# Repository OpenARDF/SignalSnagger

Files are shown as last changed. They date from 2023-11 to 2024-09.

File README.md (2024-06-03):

# SignalSnagger
<b>Project Status</b>

SignalSnagger is still in development. Product design and BOM contents are preliminary and incomplete.

<b>Concept</b>

SignalSnagger is an 80-meter band radio orienteering (ARDF) direction-finding receiver designed to operate in the Amateur Radio Service 3.5 MHz to 3.7 MHz frequency range. The receiver is designed to perform well in all common radio orienteering event formats: classic, sprint, and foxoring. SignalSnagger's frequency is stable and accurate using a precision temperature-compensated signal generator. A tuned loop with a "sense antenna," based on Dale Hunt's WB6BYU proven design, provides reliable signal-direction readings over a wide range of signal levels. This is an affordable, modern, competition-grade receiver design.

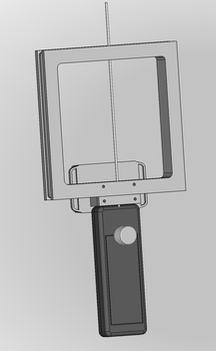
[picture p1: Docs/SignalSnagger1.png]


<b>Mechanical Design</b>

The mechanical design is optimized for simplicity, ruggedness, and ergonomic comfort. Left/right symmetry makes the receiver equally usable for left and right handers. Only the front knob (attached to a rotary encoder) extends beyond the walls of the chassis box, helping to minimize the risk of damage during transport or if dropped. Aside from the wires running to the battery, there is no point-to-point wiring - all connections are handled by PCB traces and parts mounted to the circuit board, eliminating unreliable point-to-point wiring. The headphone jack is on the bottom of the receiver, preventing water intrusion. The square antenna geometry makes for a stronger loop that can be readily fabricated using 3D printing. Switches for sense and configuration are recessed and immune to water penetration. The battery can be charged or replaced without opening the receiver chassis. If something breaks or wears out, all parts are readily available from online vendors, and the schematic diagram and BOM are provided, facilitating customer troubleshooting and repair.

<b>Electronics Design</b>

The electronics design is optimized to avoid part obsolescence and to provide high performance. SignalSlinger uses a Software Defined Radio design, utilizing a quadrature sampling detector to provide high dynamic range and to maximize software-upgradable features. A 25-MHz processor capable of sampling the baseband signal can filter and process the audio to achieve reliable signal strength indication and signal detection and supports DSP algorithms to achieve unparalleled SNR performance to detect weak signals deep in the noise.

<b>Free and Open Design</b>

The SignalSlinger project is 100% Open Source. All software and hardware design documents can be downloaded from this GitHub repository.

BOM: https://docs.google.com/spreadsheets/d/1Z3T1SeX6hfT8fjVtJgXu2S2YWHPFD_kywdSzAihOS8g/edit?usp=sharing

Also, check out SignalSnagger's sibling transmitter project: <a href="https://github.com/OpenARDF/SignalSlinger">SignalSlinger</a>.

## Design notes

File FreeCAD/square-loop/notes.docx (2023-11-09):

A square loop frame.

Grooved channels should allow the flat ribbon cable to lay flat in the channel with the pickup coax in a lower channel below the ribbon cable. No need to try forcing bending a flat cable into a round structure. The coax can be put in place first, then the ribbon cable on top. A much easier installation. The original design with a round loop had issues getting the ribbon cable installed and formed to match the curved surface simultaneously and keeping the coax well aligned in the bundle. It was very challenging to work with.

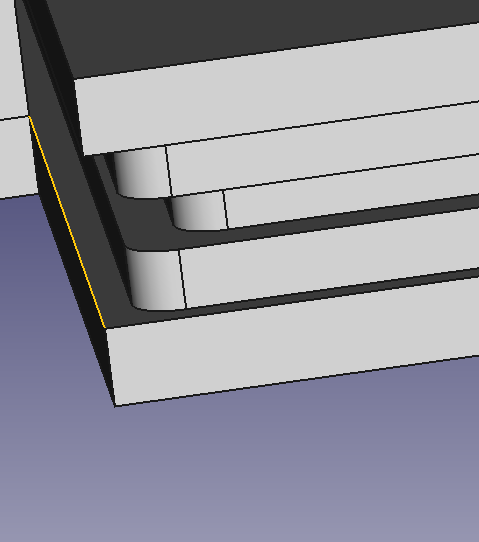
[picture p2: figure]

Flat Cable grove

Install coax first and

Then install Flat cable. This covers the coax.

Rounded edges to help cable make the bend.

Coax grove

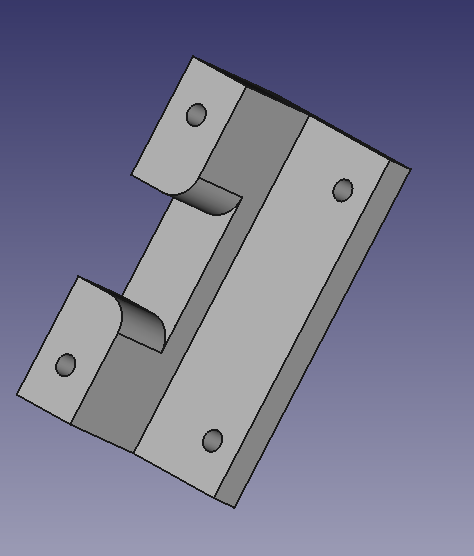
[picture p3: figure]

Bottom view of L block clamp showing rounded edges to help cable bend.

Loop main frame. No gluing or C clamps are required for the loop frame assembly. Printed as a single assembly. It will have more capture area than Dale’s original receiver. It should be closer to the rig expert FoxRex receiver.

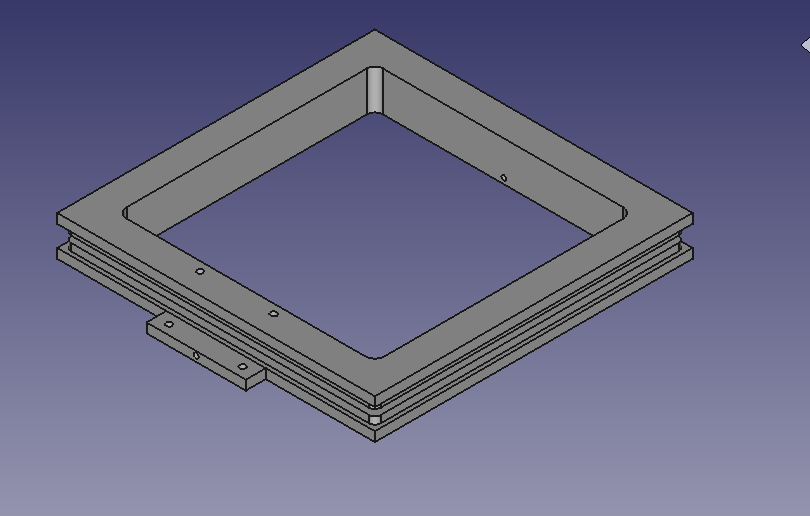
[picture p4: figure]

L block clamp.

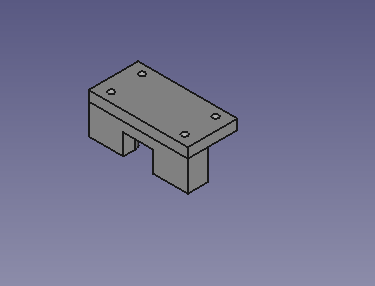
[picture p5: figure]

Complete assembly showing sense antenna installed.

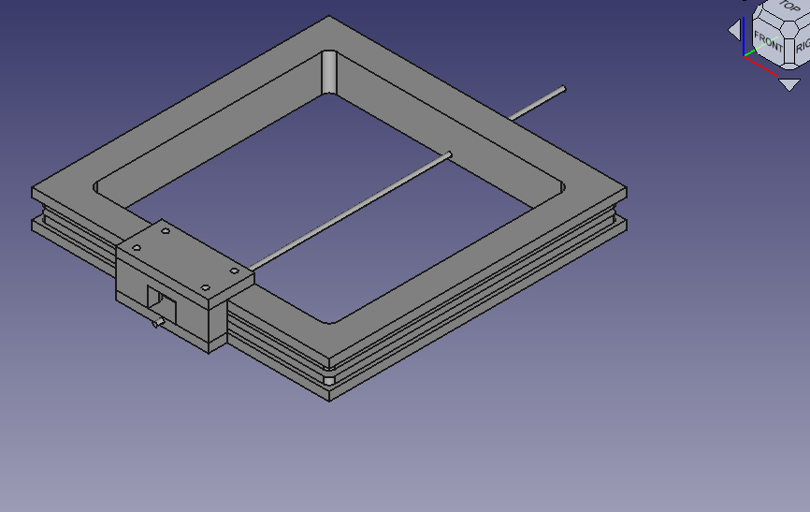
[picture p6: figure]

This will bolt onto the receiver box adaptor fixture.

Via the 4 bolt holes. 4 each 4-40 hardware. Attaches both the L clamp and loop frame to the receiver box adaptor using the 4 bolts.

Sense element is made from 220 mm length of Brass welding rod

Sense element

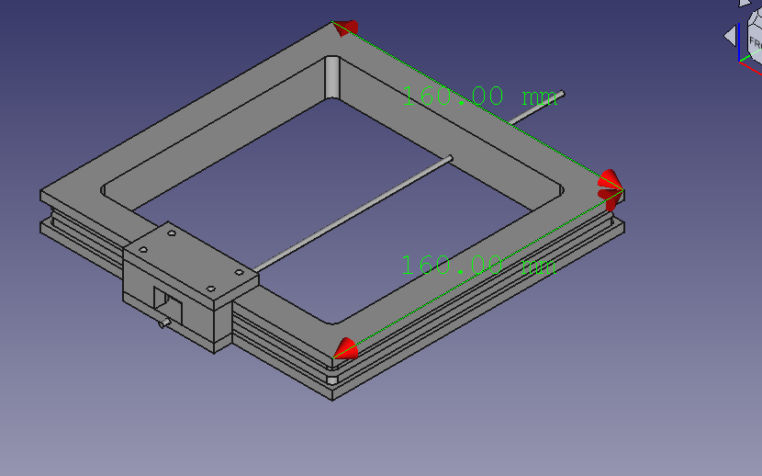
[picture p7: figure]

After running the Prusa printer slicer software using support material, the estimated print time will be 9H 35 seconds.

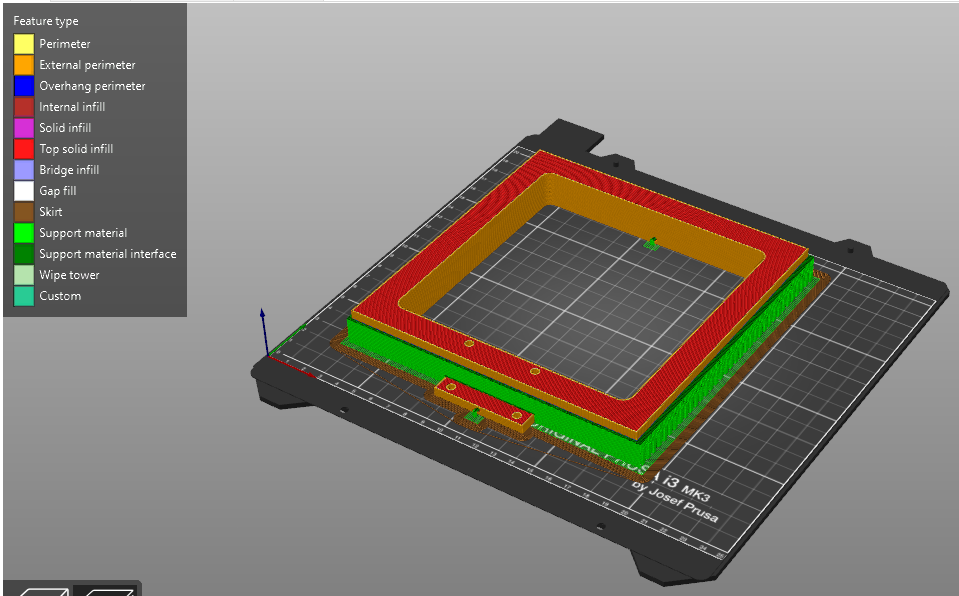
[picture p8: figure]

The Gcode files are for use with a Prusa printer.

The MF files are the Prusa printer slicer project files. If using another printer, start with the STL files and then prepare for your printer (slicing and adding printing supports for the loop.

Given the print size, I think it is possible to print a slide-on cover covering the ribbon. Will wait to see how the loop works (electrically and in the field) before designing that.

This design should be printable on most printers. I have a higher-end unit and print using PTEG material. It’s more robust and heat resistant.

A square loop frame is different from traditional round radio-O loops and is cool looking. It looks like photos from the early days of radio.

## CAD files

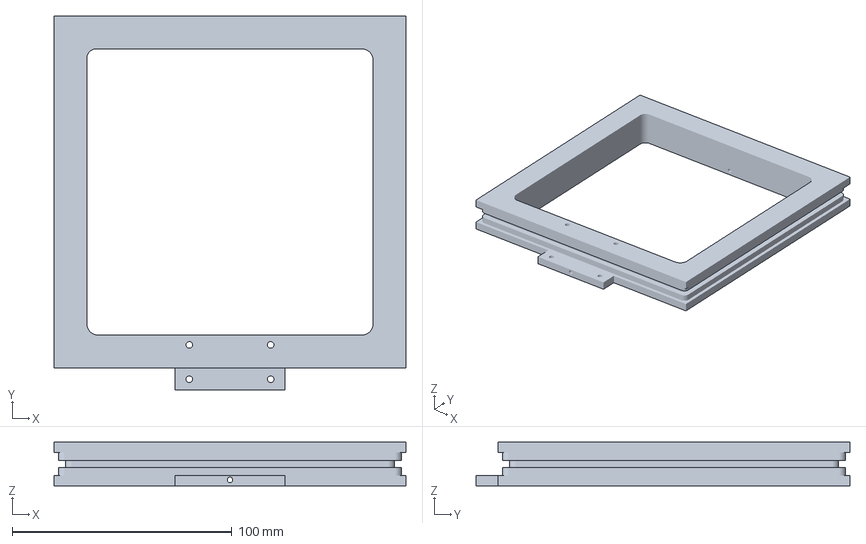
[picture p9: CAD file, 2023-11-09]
FreeCAD/square-loop/square-loop-loop-main-top.3mf
160.0 x 170.0 x 20.0 mm

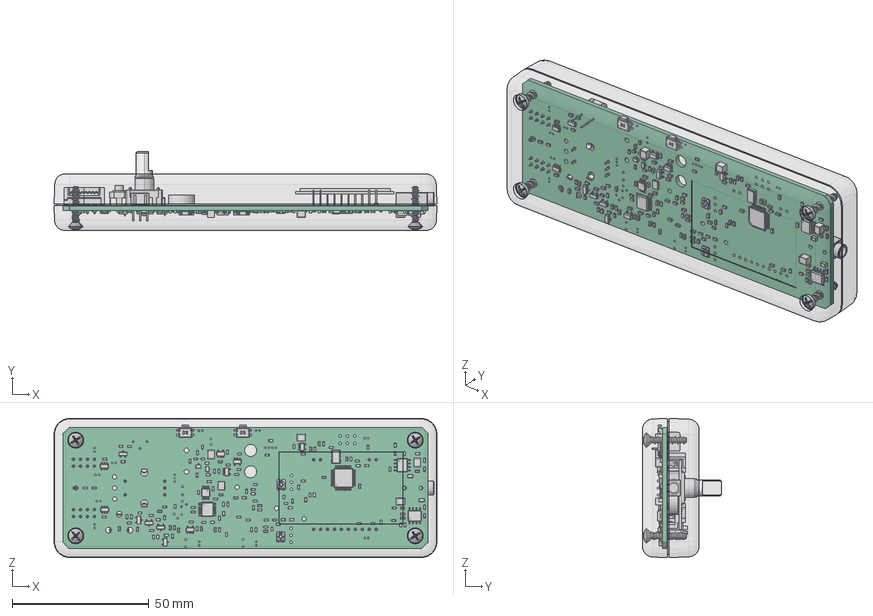
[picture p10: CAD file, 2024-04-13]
FreeCAD/PCB.FCStd
139.8 x 28.9 x 50.8 mm
Pcb_f029
C309_C_0603_1608Metric_5b6584633696 x 70
D202_D_SOD_523_5f1e31624493 x 3
R308_R_0603_1608Metric_2646eda285c6 x 56
Q104_SOT_23_06d05efaf5e9 x 5
C211_C_1210_3225Metric_024b47ac60aa x 4
U202_MSOP_10_3x3mm_P05mm_6a2b85d260ff
U304_SOIC_8_39x49mm_P127mm_a25c1b85c3f7 x 2
C912_C_0805_2012Metric_1626aba29b16 x 2
U103_SOT_23_5_ef80d484d645 x 5
U105_TSOP_6_165x305mm_P095mm_c201cc63ee81 x 2
P410002_Shrinkwrap_1 x 2
P410002_Shrinkwrap_002 x 2
P410002_Shrinkwrap_003 x 2
X202_Crystal_SMD_Abracon_ABM8G-4Pin_3.2x2.5mm_3b3a4259f167
U102_SSOP_16_44x52mm_P065mm_e96945418c2c
U201_TQFP_48_7x7mm_P05mm_968e8baed286
Q202_SOT_323_SC_70_05efad48121b x 2
L201_L_0603_1608Metric_e3fa5a9bdcec
TC33X-2-202E x 2
TC33X-2-202E001 x 2
TC33X-2-202E002 x 2
TC33X-2-202E003 x 2
TC33X-2-202E004 x 2
TC33X-2-202E005 x 2
TC33X-2-202E006 x 2
TC33X-2-202E007 x 2
Oscillator_SMD_Fox_FT5H_5.0x3.2mm
Oscillator_SMD_Fox_FT5H_5.0x3.2mm001
Oscillator_SMD_Fox_FT5H_5.0x3.2mm002
C103_top-cap_a8b6c266b834
SW203_pec12r-4225f-s0024_5a24d6cbfc16
D203_LED_0805_2012Metric_1174dec2679d x 2
U205_Body_sp_fa2d59fb00e0
69830_20P_BODY_1_AF0_1_AF0 x 2
69830_20P_COVER_1_AF0_1_AF0 x 2
69830_20P_BODY_1_AF0_1_AF0_1 x 2
69830_20P_COVER_1_AF0_1_AF0_1 x 2
J301_35RASMT2BHSNTRX_d01fbb62650b
T101_37-43_8862338c664e
RV101_3362A_TAA_384ee5cac117
KT-70C_KT-70TC001
SCREWS-HL5~8-BR
KT-70B_KT-70BXX
SCREWS-HL5~8-BR001
SCREWS-HL5~8-BR002
SCREWS-HL5~8-BR003

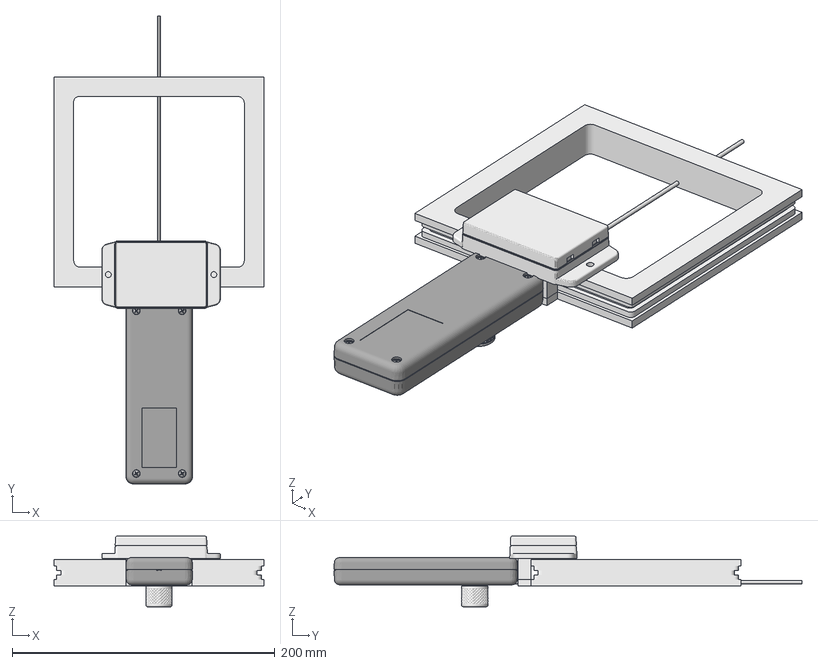
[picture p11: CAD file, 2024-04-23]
FreeCAD/square-loop/square-loop.FCStd
160.0 x 356.5 x 53.8 mm
lblock-top
loop-main-top
Pcb_f029
C309_C_0603_1608Metric_5b6584633696 x 70
D202_D_SOD_523_5f1e31624493 x 3
R308_R_0603_1608Metric_2646eda285c6 x 56
Q104_SOT_23_06d05efaf5e9 x 5
C211_C_1210_3225Metric_024b47ac60aa x 4
U202_MSOP_10_3x3mm_P05mm_6a2b85d260ff
U304_SOIC_8_39x49mm_P127mm_a25c1b85c3f7 x 2
C912_C_0805_2012Metric_1626aba29b16 x 2
U103_SOT_23_5_ef80d484d645 x 5
U105_TSOP_6_165x305mm_P095mm_c201cc63ee81 x 2
P410002_Shrinkwrap_1 x 2
P410002_Shrinkwrap_002 x 2
P410002_Shrinkwrap_003 x 2
X202_Crystal_SMD_Abracon_ABM8G-4Pin_3.2x2.5mm_3b3a4259f167
U102_SSOP_16_44x52mm_P065mm_e96945418c2c
U201_TQFP_48_7x7mm_P05mm_968e8baed286
Q202_SOT_323_SC_70_05efad48121b x 2
L201_L_0603_1608Metric_e3fa5a9bdcec
TC33X-2-202E x 2
TC33X-2-202E001 x 2
TC33X-2-202E002 x 2
TC33X-2-202E003 x 2
TC33X-2-202E004 x 2
TC33X-2-202E005 x 2
TC33X-2-202E006 x 2
TC33X-2-202E007 x 2
Oscillator_SMD_Fox_FT5H_5.0x3.2mm
Oscillator_SMD_Fox_FT5H_5.0x3.2mm001
Oscillator_SMD_Fox_FT5H_5.0x3.2mm002
C103_top-cap_a8b6c266b834
SW203_pec12r-4225f-s0024_5a24d6cbfc16
D203_LED_0805_2012Metric_1174dec2679d x 2
U205_Body_sp_fa2d59fb00e0
69830_20P_BODY_1_AF0_1_AF0 x 2
69830_20P_COVER_1_AF0_1_AF0 x 2
69830_20P_BODY_1_AF0_1_AF0_1 x 2
69830_20P_COVER_1_AF0_1_AF0_1 x 2
J301_35RASMT2BHSNTRX_d01fbb62650b
T101_37-43_8862338c664e
RV101_3362A_TAA_384ee5cac117
KT-70C_KT-70TC001
SCREWS-HL5~8-BR
KT-70B_KT-70BXX
SCREWS-HL5~8-BR001
SCREWS-HL5~8-BR002
SCREWS-HL5~8-BR003
450mAh LiPo
SN-23B_SN-23B-01
SN-23C_SN-23C-01
20mm

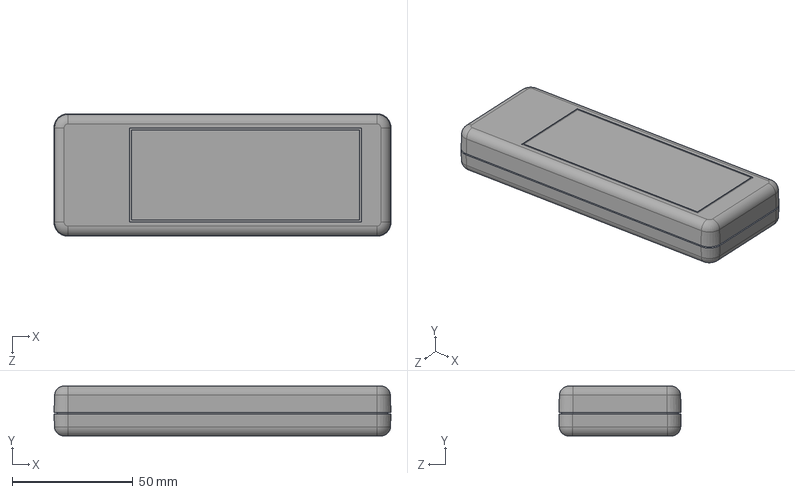
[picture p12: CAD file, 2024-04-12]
FreeCAD/KT-70XXT0 ASS'Y.STEP
139.8 x 20.7 x 50.8 mm
KT-70C_KT-70TC0
SCREWS-HL5~8-BR x 4
KT-70B_KT-70BXX

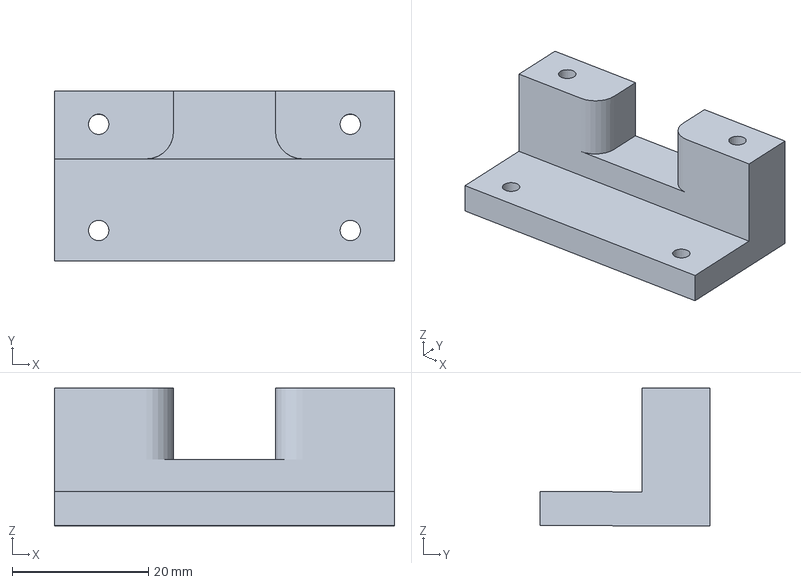
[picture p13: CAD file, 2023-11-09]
FreeCAD/square-loop/lblock-top.3mf
50.0 x 25.0 x 20.3 mm

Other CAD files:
FreeCAD/square-loop/lblock-top.stl
FreeCAD/square-loop/square-loop-loop-main-top.stl

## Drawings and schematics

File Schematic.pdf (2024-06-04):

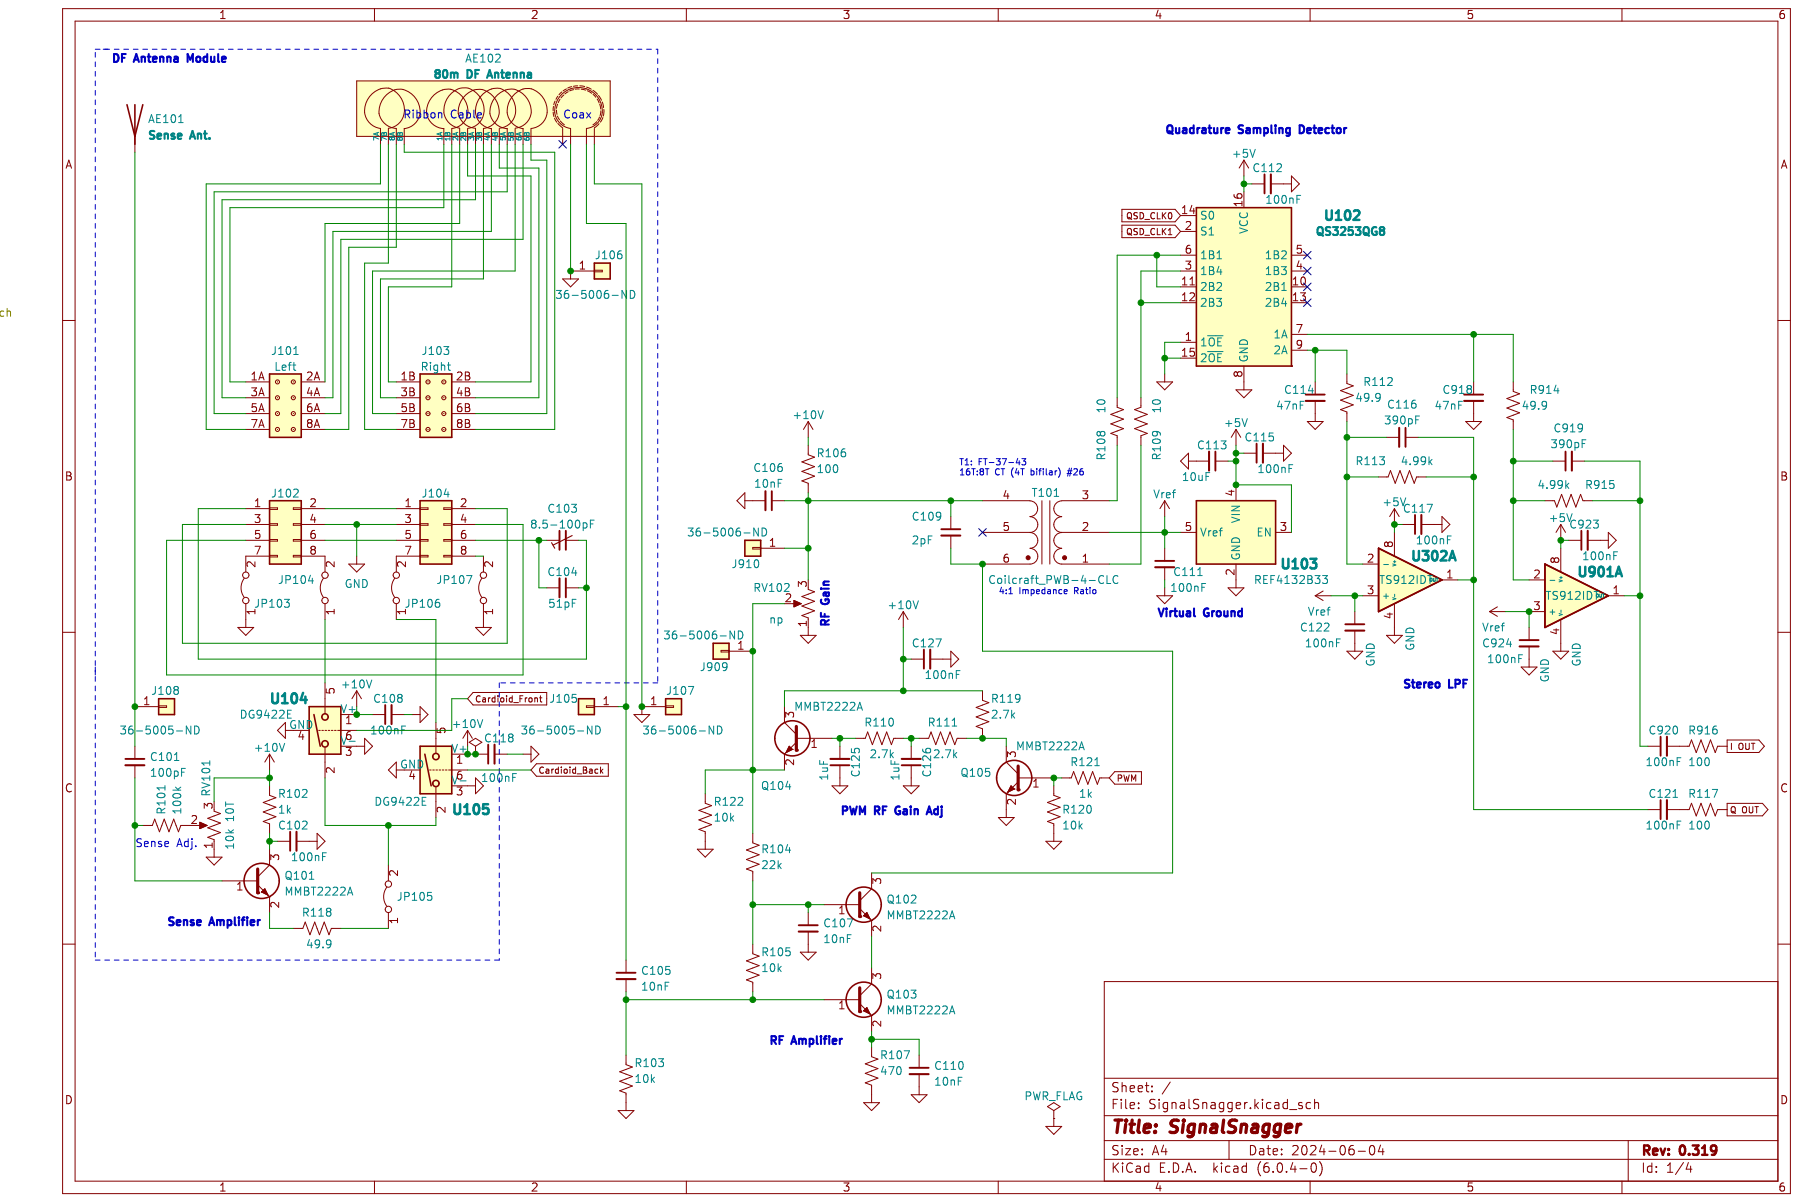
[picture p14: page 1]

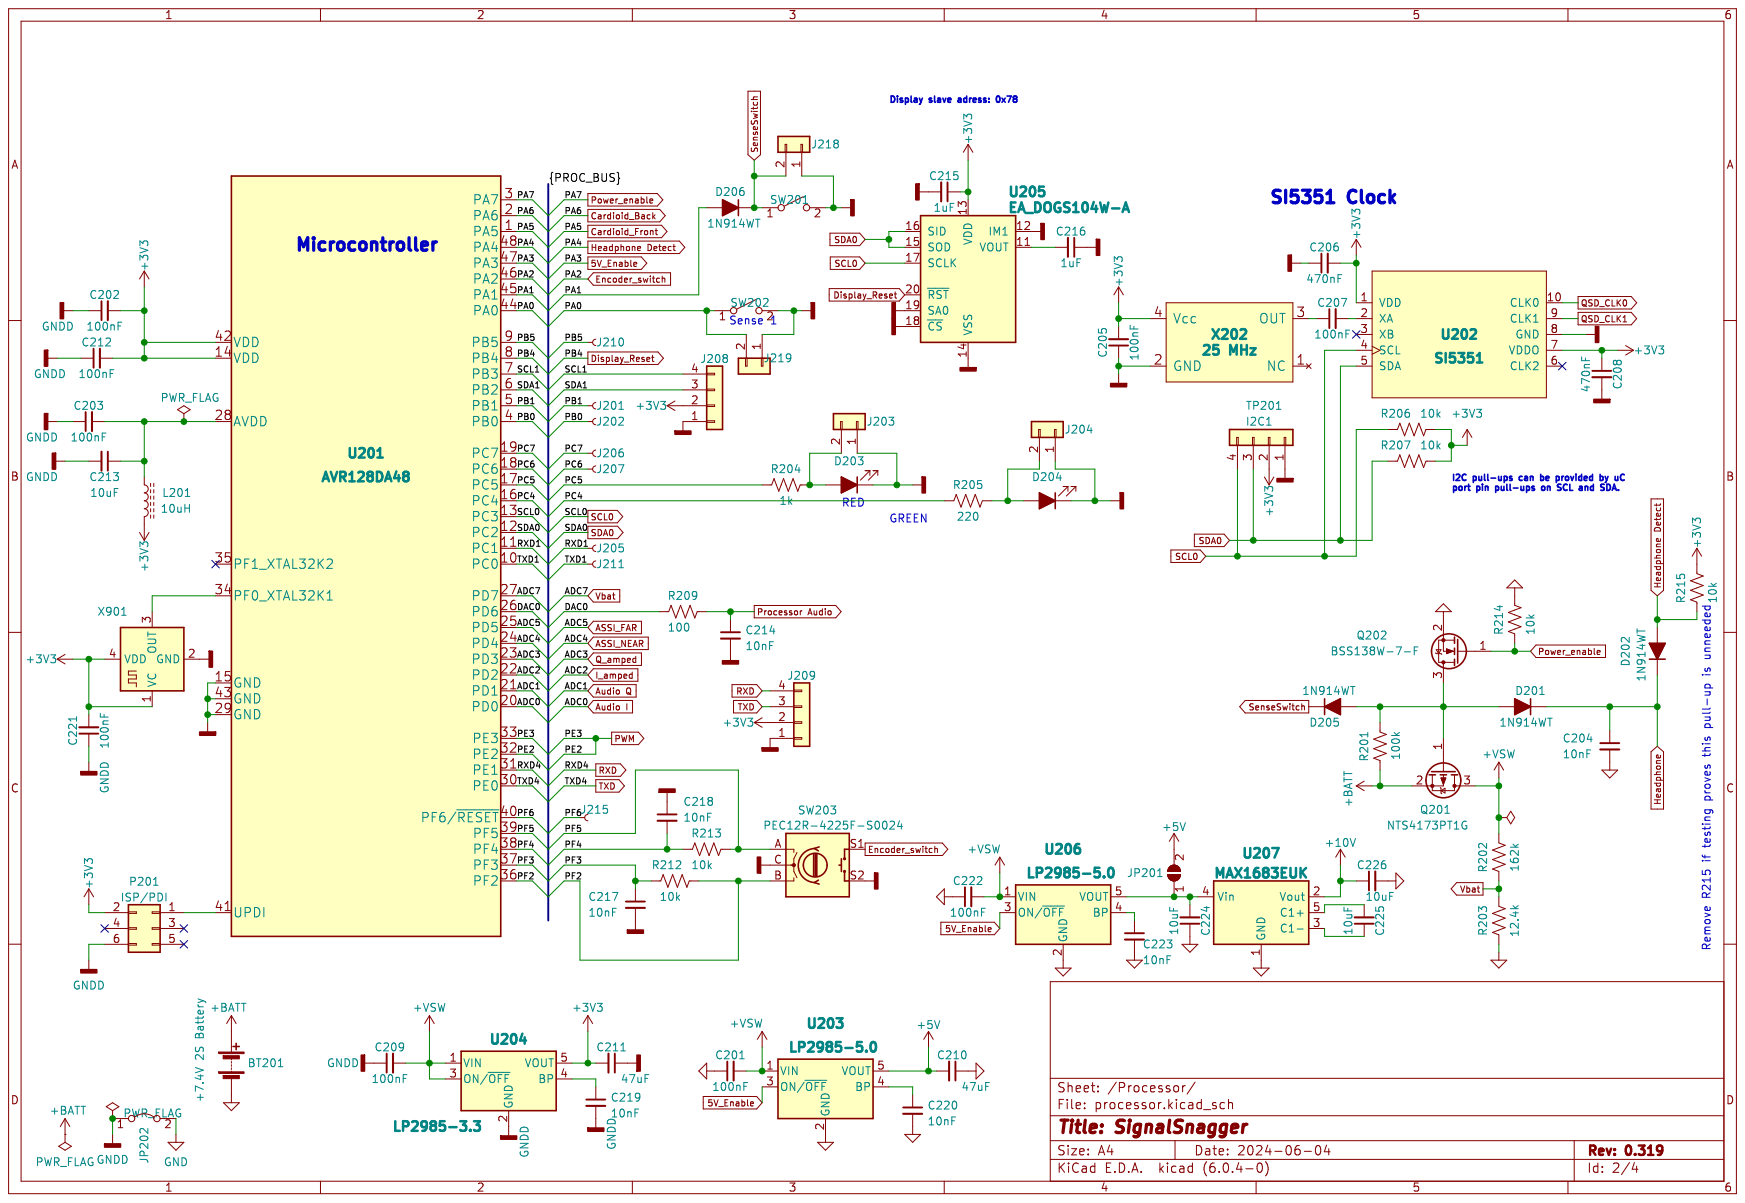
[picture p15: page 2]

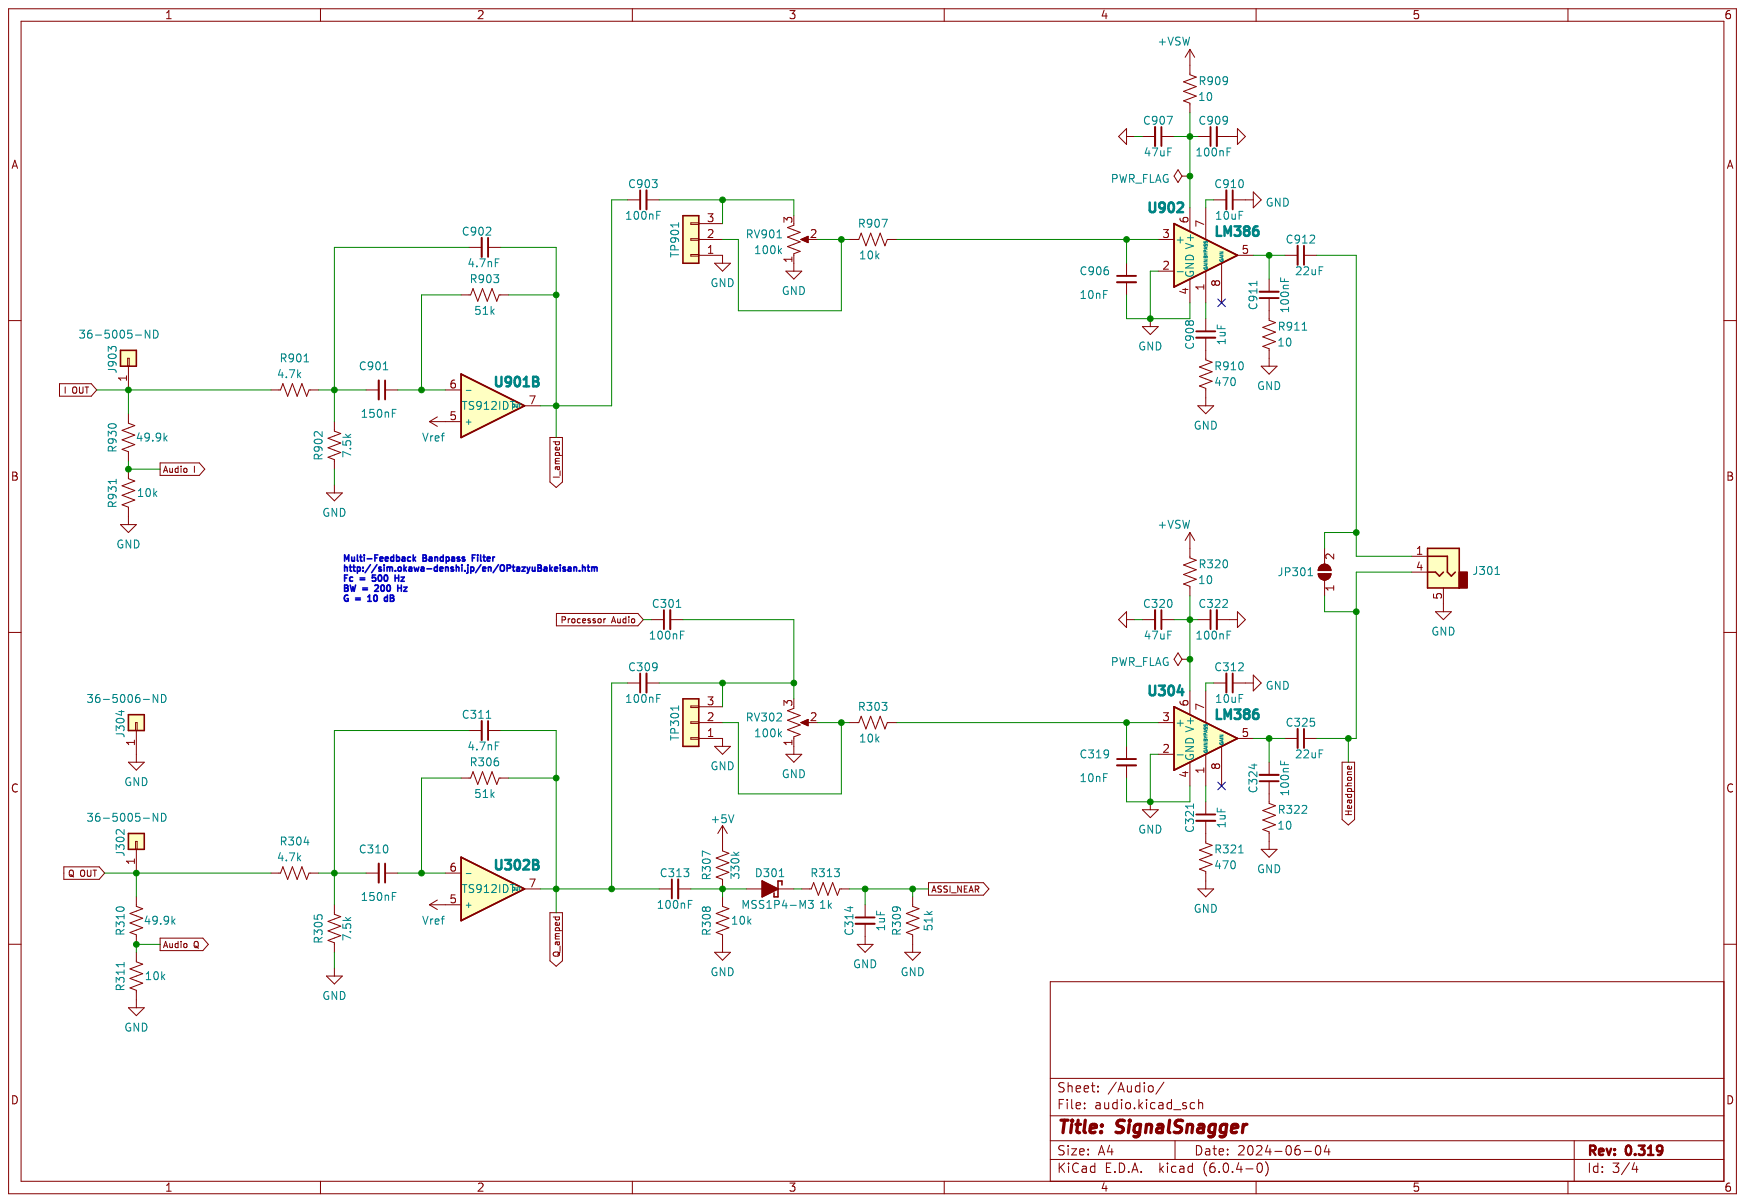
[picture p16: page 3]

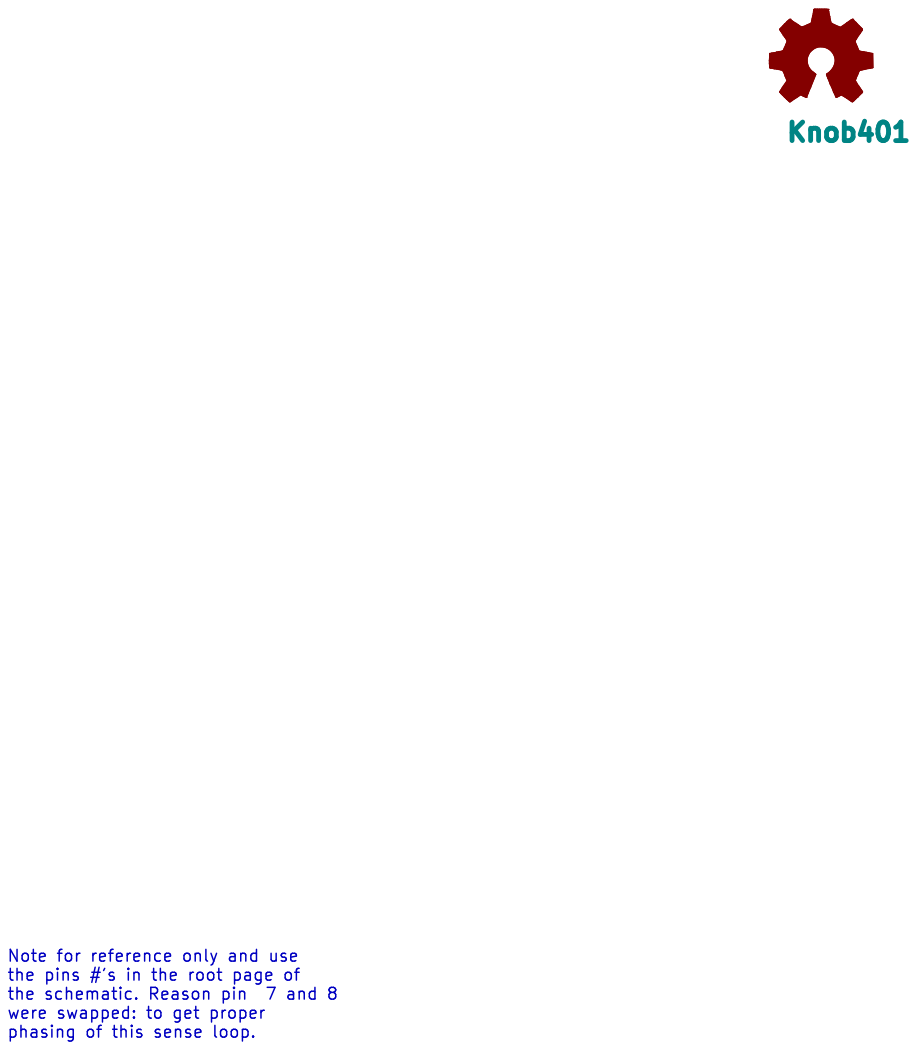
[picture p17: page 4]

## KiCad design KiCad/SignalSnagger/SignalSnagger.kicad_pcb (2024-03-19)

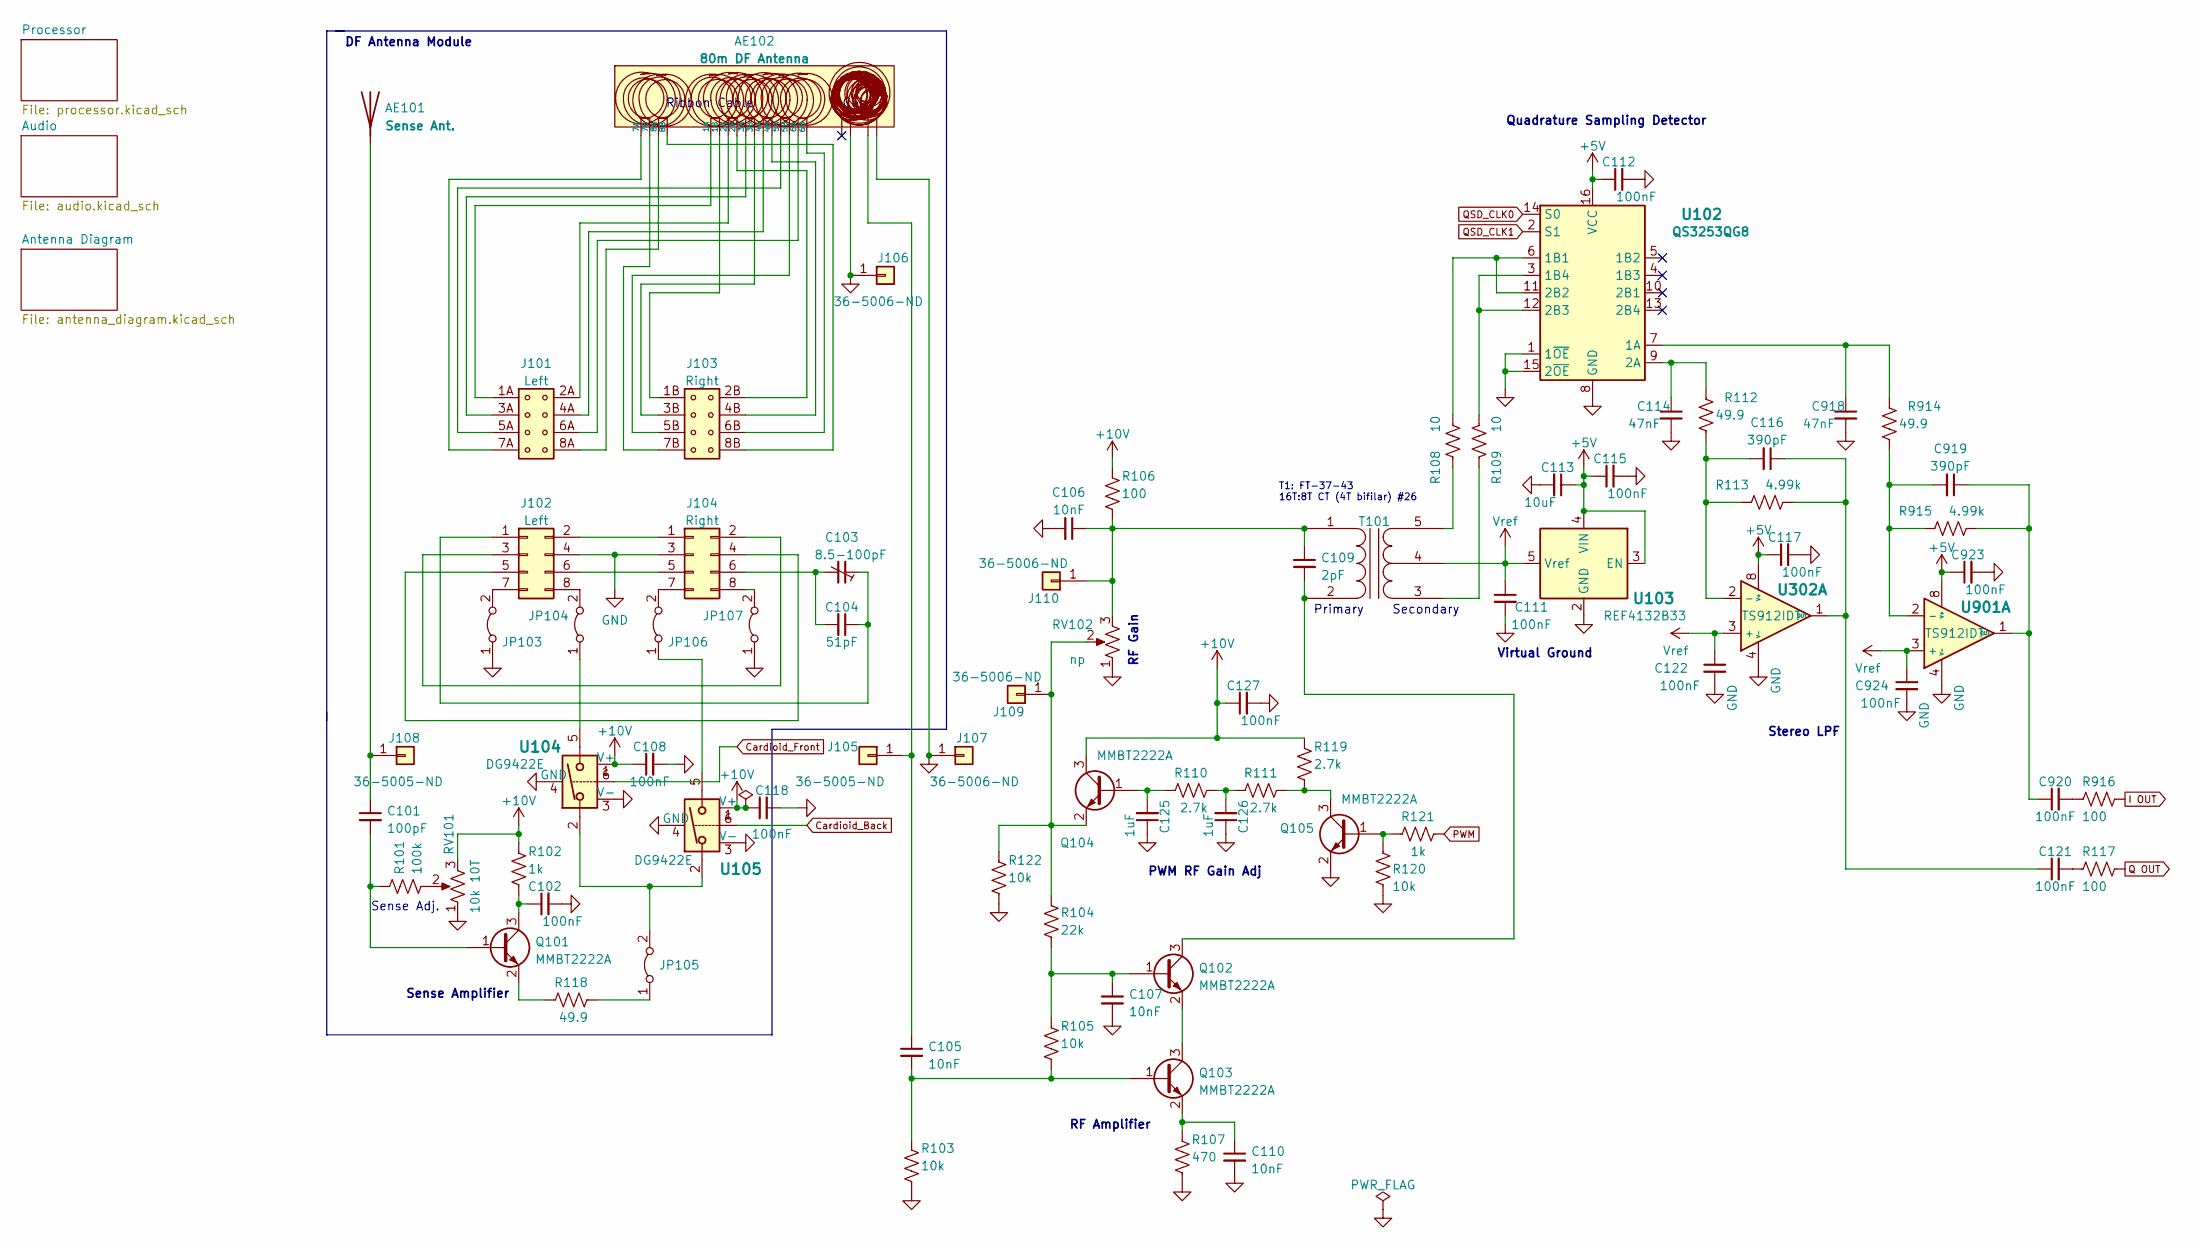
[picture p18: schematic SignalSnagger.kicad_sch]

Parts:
AE101: Sense Ant.; Dummy_Empty
AE102: 80m DF Antenna; Dummy_Empty
C101: 100pF; C_0603_1608Metric; Manufacturer PN CC0603JRNPO9BN101; Digi-Key Part No. 311-1069-1-ND
C102, C108, C111, C112, C115, C117, C118, C121, C122, C127, C920, C923, C924: 100nF; C_0603_1608Metric; Manufacturer PN CL10B104KA8NNNC; Digi-Key Part No. 1276-1006-1-ND
C103: 8.5-100pF; VC07B; Manufacturer PN CTC07RB-100; Digi-Key Part No. N/P
C104: 51pF; C_0603_1608Metric; Manufacturer PN CL10C510JB8NNNC; Digi-Key Part No. 1276-2310-1-ND
C105, C106, C107, C110: 10nF; C_0603_1608Metric; Manufacturer PN C0603X103J4HACAUTO; Digi-Key Part No. 399-C0603X103J4HACAUTOCT-ND
C109: 2pF; C_0603_1608Metric; Manufacturer PN 06035A2R0JAT2A; Digi-Key Part No. 478-11610-1-ND
C113: 10uF; C_0603_1608Metric; Manufacturer PN GRM188C81C106MA73D; Digi-Key Part No. 490-7198-1-ND
C114, C918: 47nF; C_0603_1608Metric; Manufacturer PN C0603X473J4RECAUTO7411; Digi-Key Part No. 399-C0603X473J4RECAUTO7411CT-ND
C116, C919: 390pF; C_0603_1608Metric; Manufacturer PN CC0603JRNPO9BN391; Digi-Key Part No. 311-1076-1-ND
C125, C126: 1uF; C_0603_1608Metric; Manufacturer PN CC0603KRX5R8BB105; Digi-Key Part No. 311-1445-1-ND
J101: Left; Dummy_Empty
J102: Left; PinHeader_2x04_P2.54mm_Vertical; Digi-Key Part No. N/P
J103: Right; Dummy_Empty
J104: Right; PinHeader_2x04_P2.54mm_Vertical; Digi-Key Part No. N/P
J105, J108: 36-5005-ND; Pin_D1.6mm_L8.5mm_W2.8mm_FlatFork; Digi-Key Part No. N/P
J106, J107, J109, J110: 36-5006-ND; Pin_D1.6mm_L8.5mm_W2.8mm_FlatFork; Digi-Key Part No. N/P
JP103, JP104, JP106, JP107: Digi-Key Part No. N/P
JP105: Jumper_2_Bridged; Jumper_THT-1x02_Bridged_Circular; Digi-Key Part No. N/P
Q101, Q102, Q103, Q104, Q105: MMBT2222A; SOT-23; Manufacturer PN SMMBT2222ALT1G; Digi-Key Part No. SMMBT2222ALT1GOSCT-ND
R101: 100k; R_0603_1608Metric; Manufacturer PN RC0603FR-07100KL; Digi-Key Part No. 311-100KHRCT-ND
R102, R121: 1k; R_0603_1608Metric; Manufacturer PN RC0603FR-071KL; Digi-Key Part No. 311-1.00KHRCT-ND
R103, R105, R120, R122: 10k; R_0603_1608Metric; Manufacturer PN RC0603FR-0710KL; Digi-Key Part No. 311-10.0KHRCT-ND
R104: 22k; R_0603_1608Metric; Manufacturer PN RC0603FR-0722KL; Digi-Key Part No. 311-22.0KHRCT-ND
R106, R117, R916: 100; R_0603_1608Metric; Manufacturer PN RC0603FR-07100RL; Digi-Key Part No. 311-100HRCT-ND
R107: 470; R_0603_1608Metric; Manufacturer PN RC0603FR-07470RL; Digi-Key Part No. 311-470HRCT-ND
R108, R109: 10; R_0603_1608Metric; Manufacturer PN RC0603FR-0710RL; Digi-Key Part No. 311-10.0HRCT-ND
R110, R111, R119: 2.7k; R_0603_1608Metric; Manufacturer PN RC0603FR-072K7L; Digi-Key Part No. 311-2.70KHRCT-ND
R112, R118, R914: 49.9; R_0603_1608Metric; Manufacturer PN ERJ-3EKF49R9V; Digi-Key Part No. P49.9HCT-ND
R113, R915: 4.99k; R_0603_1608Metric; Manufacturer PN RC0603FR-074K99L; Digi-Key Part No. 311-4.99KHRCT-ND
RV101: 10k 10T; Bourns_PV36W_Multiturn_Pot; Manufacturer PN PV36W103C01B00; Digi-Key Part No. 118-PV36W103C01B00-ND
RV102: np; PinHeader_1x03_P1.27mm_Vertical
T101: Transformer_1P_SS; FT-37_Core_3_windings_Horiz_TH; Digi-Key Part No. N/P
U102: QS3253QG8; SSOP-16_3.9x4.9mm_P0.635mm; Manufacturer PN PI5C3253QEX; Digi-Key Part No. PI5C3253QEXDICT-ND
U103: REF4132B33; SOT-23-5; Manufacturer PN REF4132B33DBVR; Digi-Key Part No. 296-REF4132B33DBVRCT-ND
U104, U105: DG9422E; TSOP-6_1.65x3.05mm_P0.95mm; Manufacturer PN DG9422EDV-T1-GE3; Digi-Key Part No. DG9422EDV-T1-GE3CT-ND
U302, U901: TS912IDT; SO-8_3.9x4.9mm_P1.27mm; Manufacturer PN TS912IDT; Digi-Key Part No. 497-6618-1-ND

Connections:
+5V: C112.1, C113.1, C115.1, C117.1, C923.1, U102.16 (VCC), U103.3 (EN), U103.4 (VIN), U302.8 (V+), U901.8 (V+); also elsewhere on the board
+10V: C108.1, C118.1, C127.1, Q104.3 (C), R102.1, R106.1, R119.1, RV101.3, U104.1 (V+), U105.1 (V+); also elsewhere on the board
Cardioid_Back: U105.6; also elsewhere on the board
Cardioid_Front: U104.6; also elsewhere on the board
GND: AE102.18, AE102.20, C102.2, C106.2, C107.2, C108.2, C110.2, C111.2, C112.2, C113.2, C114.2, C115.2, C117.2, C118.2, C122.2, C125.1, C126.1, C127.2, C918.2, C923.2, C924.2, J102.4, J104.3, J106.1, J107.1, JP103.1 (A), JP107.1 (A), Q105.2 (E), R103.2, R107.2, R120.2, R122.2, RV101.1, RV102.1, U102.1 (1~OE), U102.8 (GND), U102.15 (2~OE), U103.2 (GND), U104.3 (V-), U104.4 (GND), U105.3 (V-), U105.4 (GND), U302.4 (V-), U901.4 (V-); also elsewhere on the board
I OUT: R916.2; also elsewhere on the board
unnamed: AE101.1, C101.1, J108.1
unnamed: AE102.1 (7A), J101.7A (Pin_7)
unnamed: AE102.2 (7B), J103.7B (Pin_7)
unnamed: AE102.3 (8A), J101.8A (Pin_8)
unnamed: AE102.4 (8B), J103.8B (Pin_8)
unnamed: AE102.5 (1A), J101.1A (Pin_1)
unnamed: AE102.6 (1B), J103.1B (Pin_1)
unnamed: AE102.7 (2A), J101.2A (Pin_2)
unnamed: AE102.8 (2B), J103.2B (Pin_2)
unnamed: AE102.9 (3A), J101.3A (Pin_3)
unnamed: AE102.10 (3B), J103.3B (Pin_3)
unnamed: AE102.11 (4A), J101.4A (Pin_4)
unnamed: AE102.12 (4B), J103.4B (Pin_4)
unnamed: AE102.13 (5A), J101.5A (Pin_5)
unnamed: AE102.14 (5B), J103.5B (Pin_5)
unnamed: AE102.15 (6A), J101.6A (Pin_6)
unnamed: AE102.16 (6B), J103.6B (Pin_6)
unnamed 60: AE102.19, C105.1, J105.1; also elsewhere on the board
unnamed: C101.2, Q101.1 (B), R101.1
unnamed: C102.1, Q101.3 (C), R102.2
unnamed: C103.1, C104.1, J102.1
unnamed: C103.2, C104.2, J104.6
unnamed 65: C105.2, Q103.1 (B), R103.1, R105.2; also elsewhere on the board
unnamed: C106.1, C109.1, J110.1, R106.2, RV102.3, T101.1 (AA)
unnamed: C107.1, Q102.1 (B), R104.2, R105.1
unnamed: C109.2, Q102.3 (C), T101.2 (AB)
unnamed: C110.1, Q103.2 (E), R107.1
unnamed: C114.1, R112.2, U102.9 (2A)
unnamed: C116.1, C121.1, R113.1, U302.1 (OUT)
unnamed: C116.2, R112.1, R113.2, U302.2 (-)
unnamed: C121.2, R117.1
unnamed: C125.2, Q104.1 (B), R110.1
unnamed: C126.2, R110.2, R111.1
unnamed: C918.1, R914.2, U102.7 (1A)
unnamed: C919.1, C920.1, R915.1, U901.1 (OUT)
unnamed: C919.2, R914.1, R915.2, U901.2 (-)
unnamed: C920.2, R916.1
unnamed: J102.2, J104.1
unnamed: J102.3, J104.2
unnamed: J102.5, J104.4
unnamed: J102.6, J104.5
unnamed: J102.7, JP103.2 (B)
unnamed: J102.8, JP104.2 (B)
unnamed: J104.7, JP106.2 (B)
unnamed: J104.8, JP107.2 (B)
unnamed: J109.1, Q104.2 (E), R104.1, R122.1, RV102.2
unnamed: JP104.1 (A), U104.5
unnamed: JP105.1 (A), R118.1
unnamed: JP105.2 (B), U104.2, U105.2
unnamed: JP106.1 (A), U105.5
unnamed: Q101.2 (E), R118.2
unnamed: Q102.2 (E), Q103.3 (C)
unnamed: Q105.1 (B), R120.1, R121.1
unnamed: Q105.3 (C), R111.2, R119.2
unnamed: R101.2, RV101.2
unnamed: R108.1, U102.6 (1B1), U102.11 (2B2)
unnamed: R108.2, T101.5 (SB)
unnamed: R109.1, U102.3 (1B4), U102.12 (2B3)
unnamed: R109.2, T101.3 (SA)
PWM: R121.2; also elsewhere on the board
Q OUT: R117.2; also elsewhere on the board
QSD_CLK0: U102.14 (S0); also elsewhere on the board
QSD_CLK1: U102.2 (S1); also elsewhere on the board
Vref: C111.1, C122.1, C924.1, T101.4 (SC), U103.5 (Vref), U302.3 (+), U901.3 (+); also elsewhere on the board

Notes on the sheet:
DF Antenna Module
RF Gain
Stereo LPF
Secondary
Sense Amplifier
PWM RF Gain Adj
Coax
RF Amplifier
Quadrature Sampling Detector
Virtual Ground
T1: FT-37-43 16T:8T CT (4T bifilar) #26
Primary
Ribbon Cable
Sense Adj.

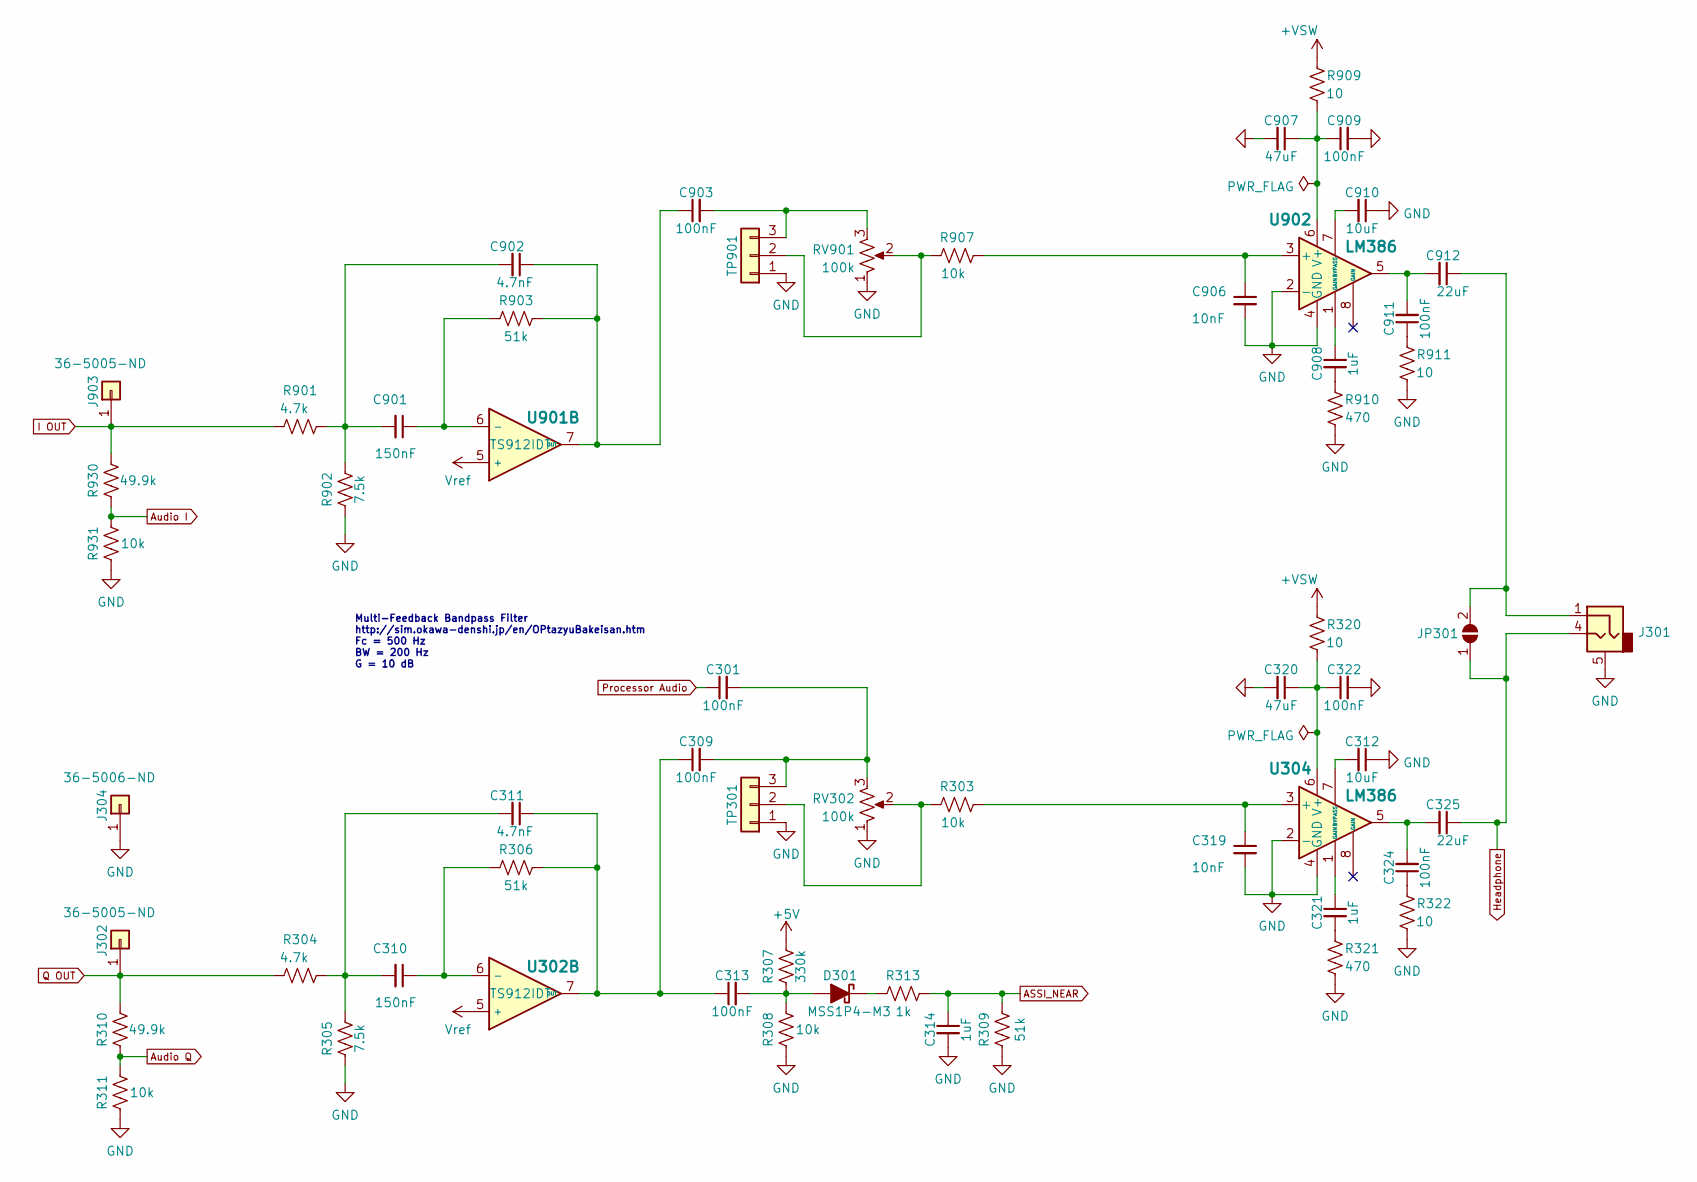
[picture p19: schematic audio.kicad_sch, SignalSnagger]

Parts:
C301, C309, C313, C322, C324, C903, C909, C911: 100nF; C_0603_1608Metric; Manufacturer PN CL10B104KA8NNNC; Digi-Key Part No. 1276-1006-1-ND
C310, C901: 150nF; C_0603_1608Metric; Manufacturer PN C0603C154J4RAC7867; Digi-Key Part No. 399-C0603C154J4RAC7867CT-ND
C311, C902: 4.7nF; C_0603_1608Metric; Manufacturer PN C0603C472K4RECAUTO; Digi-Key Part No. 399-17879-1-ND
C312, C910: 10uF; C_0603_1608Metric; Manufacturer PN GRM188C81C106MA73D; Digi-Key Part No. 490-7198-1-ND
C314, C321, C908: 1uF; C_0603_1608Metric; Manufacturer PN CC0603KRX5R8BB105; Digi-Key Part No. 311-1445-1-ND
C319, C906: 10nF; C_0603_1608Metric; Manufacturer PN C0603X103J4HACAUTO; Digi-Key Part No. 399-C0603X103J4HACAUTOCT-ND
C320, C907: 47uF; C_1210_3225Metric; Manufacturer PN CL32A476KOJNNNE; Digi-Key Part No. 1276-3376-1-ND
C325, C912: 22uF; C_0805_2012Metric; Manufacturer PN CL21A226MOQNNNE; Digi-Key Part No. 1276-2909-1-ND
D301: MSS1P4-M3; DO-219AD; Manufacturer PN MSS1P4-M3/89A; Digi-Key Part No. MSS1P4-M3/89AGICT-ND
J301: 35RASMT2BHSNTRX; SWITCHCRAFT_35RASMT2BHSNTRX; Manufacturer PN 35RASMT2BHSNTRX; Digi-Key Part No. 137-35RASMT2BHSNTRXCT-ND
J302, J903: 36-5005-ND; Pin_D1.6mm_L8.5mm_W2.8mm_FlatFork; Digi-Key Part No. N/P
J304: 36-5006-ND; Pin_D1.6mm_L8.5mm_W2.8mm_FlatFork; Digi-Key Part No. N/P
JP301: SolderJumper_2_Open; SolderJumper-2_P1.3mm_Open_RoundedPad1.0x1.5mm; Digi-Key Part No. N/P
R303, R308, R311, R907, R931: 10k; R_0603_1608Metric; Manufacturer PN RC0603FR-0710KL; Digi-Key Part No. 311-10.0KHRCT-ND
R304, R901: 4.7k; R_0603_1608Metric; Manufacturer PN RC0603FR-074K7L; Digi-Key Part No. 311-4.70KHRCT-ND
R305, R902: 7.5k; R_0603_1608Metric; Manufacturer PN RC0603FR-077K5L; Digi-Key Part No. 311-7.50KHRCT-ND
R306, R309, R903: 51k; R_0603_1608Metric; Manufacturer PN RC0603FR-0751KL; Digi-Key Part No. 311-51.0KHRCT-ND
R307: 330k; R_0603_1608Metric; Manufacturer PN RC0603FR-07330KL; Digi-Key Part No. 311-330KHRCT-ND
R310, R930: 49.9k; R_0603_1608Metric; Manufacturer PN AC0603FR-0749K9L; Digi-Key Part No. 311-49.9KLDCT-ND
R313: 1k; R_0603_1608Metric; Manufacturer PN RC0603FR-071KL; Digi-Key Part No. 311-1.00KHRCT-ND
R320, R322, R909, R911: 10; R_0603_1608Metric; Manufacturer PN RC0603FR-0710RL; Digi-Key Part No. 311-10.0HRCT-ND
R321, R910: 470; R_0603_1608Metric; Manufacturer PN RC0603FR-07470RL; Digi-Key Part No. 311-470HRCT-ND
RV302, RV901: 100k; Potentiometer_Bourns_TC33X_Vertical; Manufacturer PN TC33X-2-104E; Digi-Key Part No. TC33X-104ECT-ND
TP301, TP901: Conn_01x03; PinHeader_1x03_P2.54mm_Vertical; Digi-Key Part No. N/P
U302, U901: TS912IDT; SO-8_3.9x4.9mm_P1.27mm; Manufacturer PN TS912IDT; Digi-Key Part No. 497-6618-1-ND
U304, U902: LM386; SO-8_3.9x4.9mm_P1.27mm; Manufacturer PN LM386MX-1/NOPB; Digi-Key Part No. LM386MX-1/NOPBCT-ND

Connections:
+5V: R307.1; also elsewhere on the board
+VSW: R320.1, R909.1; also elsewhere on the board
ASSI_NEAR: C314.1, R309.2, R313.2; also elsewhere on the board
Audio I: R930.2, R931.1; also elsewhere on the board
Audio Q: R310.2, R311.1; also elsewhere on the board
GND: C312.1, C314.2, C319.2, C320.2, C322.2, C906.2, C907.2, C909.2, C910.1, J301.5, J304.1, R305.2, R308.2, R309.1, R311.2, R321.2, R322.2, R902.2, R910.2, R911.2, R931.2, RV302.1, RV901.1, TP301.1, TP901.1, U304.2 (-), U304.4 (GND), U902.2 (-), U902.4 (GND); also elsewhere on the board
Headphone: C325.1, J301.4, JP301.1 (A); also elsewhere on the board
I OUT: J903.1, R901.1, R930.1; also elsewhere on the board
unnamed: C301.2, C309.2, RV302.3, TP301.3
unnamed: C309.1, C311.1, C313.1, R306.2, U302.7 (OUT)
unnamed: C310.1, R306.1, U302.6 (-)
unnamed: C310.2, C311.2, R304.2, R305.1
unnamed: C312.2, U304.7 (BYPASS)
unnamed: C313.2, D301.2 (A), R307.2, R308.1
unnamed: C319.1, R303.2, U304.3 (+)
unnamed: C320.1, C322.1, R320.2, U304.6 (V+)
unnamed: C321.1, U304.1 (GAIN)
unnamed: C321.2, R321.1
unnamed: C324.1, R322.1
unnamed: C324.2, C325.2, U304.5
unnamed: C901.1, R903.1, U901.6 (-)
unnamed: C901.2, C902.2, R901.2, R902.1
unnamed: C902.1, C903.1, R903.2, U901.7 (OUT)
unnamed: C903.2, RV901.3, TP901.3
unnamed: C906.1, R907.2, U902.3 (+)
unnamed: C907.1, C909.1, R909.2, U902.6 (V+)
unnamed: C908.1, U902.1 (GAIN)
unnamed: C908.2, R910.1
unnamed: C910.2, U902.7 (BYPASS)
unnamed: C911.1, R911.1
unnamed: C911.2, C912.2, U902.5
unnamed: C912.1, J301.1, JP301.2 (B)
unnamed: D301.1 (K), R313.1
unnamed: R303.1, RV302.2, TP301.2
unnamed: R907.1, RV901.2, TP901.2
Processor Audio: C301.1; also elsewhere on the board
Q OUT: J302.1, R304.1, R310.1; also elsewhere on the board
Vref: U302.5 (+), U901.5 (+); also elsewhere on the board

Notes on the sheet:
Multi-Feedback Bandpass Filter http://sim.okawa-denshi.jp/en/OPtazyuBakeisan.htm Fc = 500 Hz BW = 200 Hz G = 10 dB

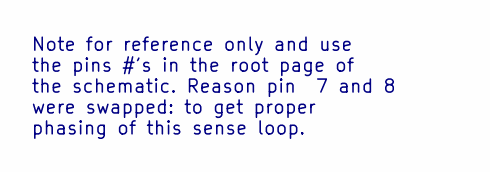
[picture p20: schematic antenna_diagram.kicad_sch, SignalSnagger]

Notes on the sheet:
Note for reference only and use the pins #'s in the root page of the schematic. Reason pin 7 and 8 were swapped: to get proper phasing of this sense loop.

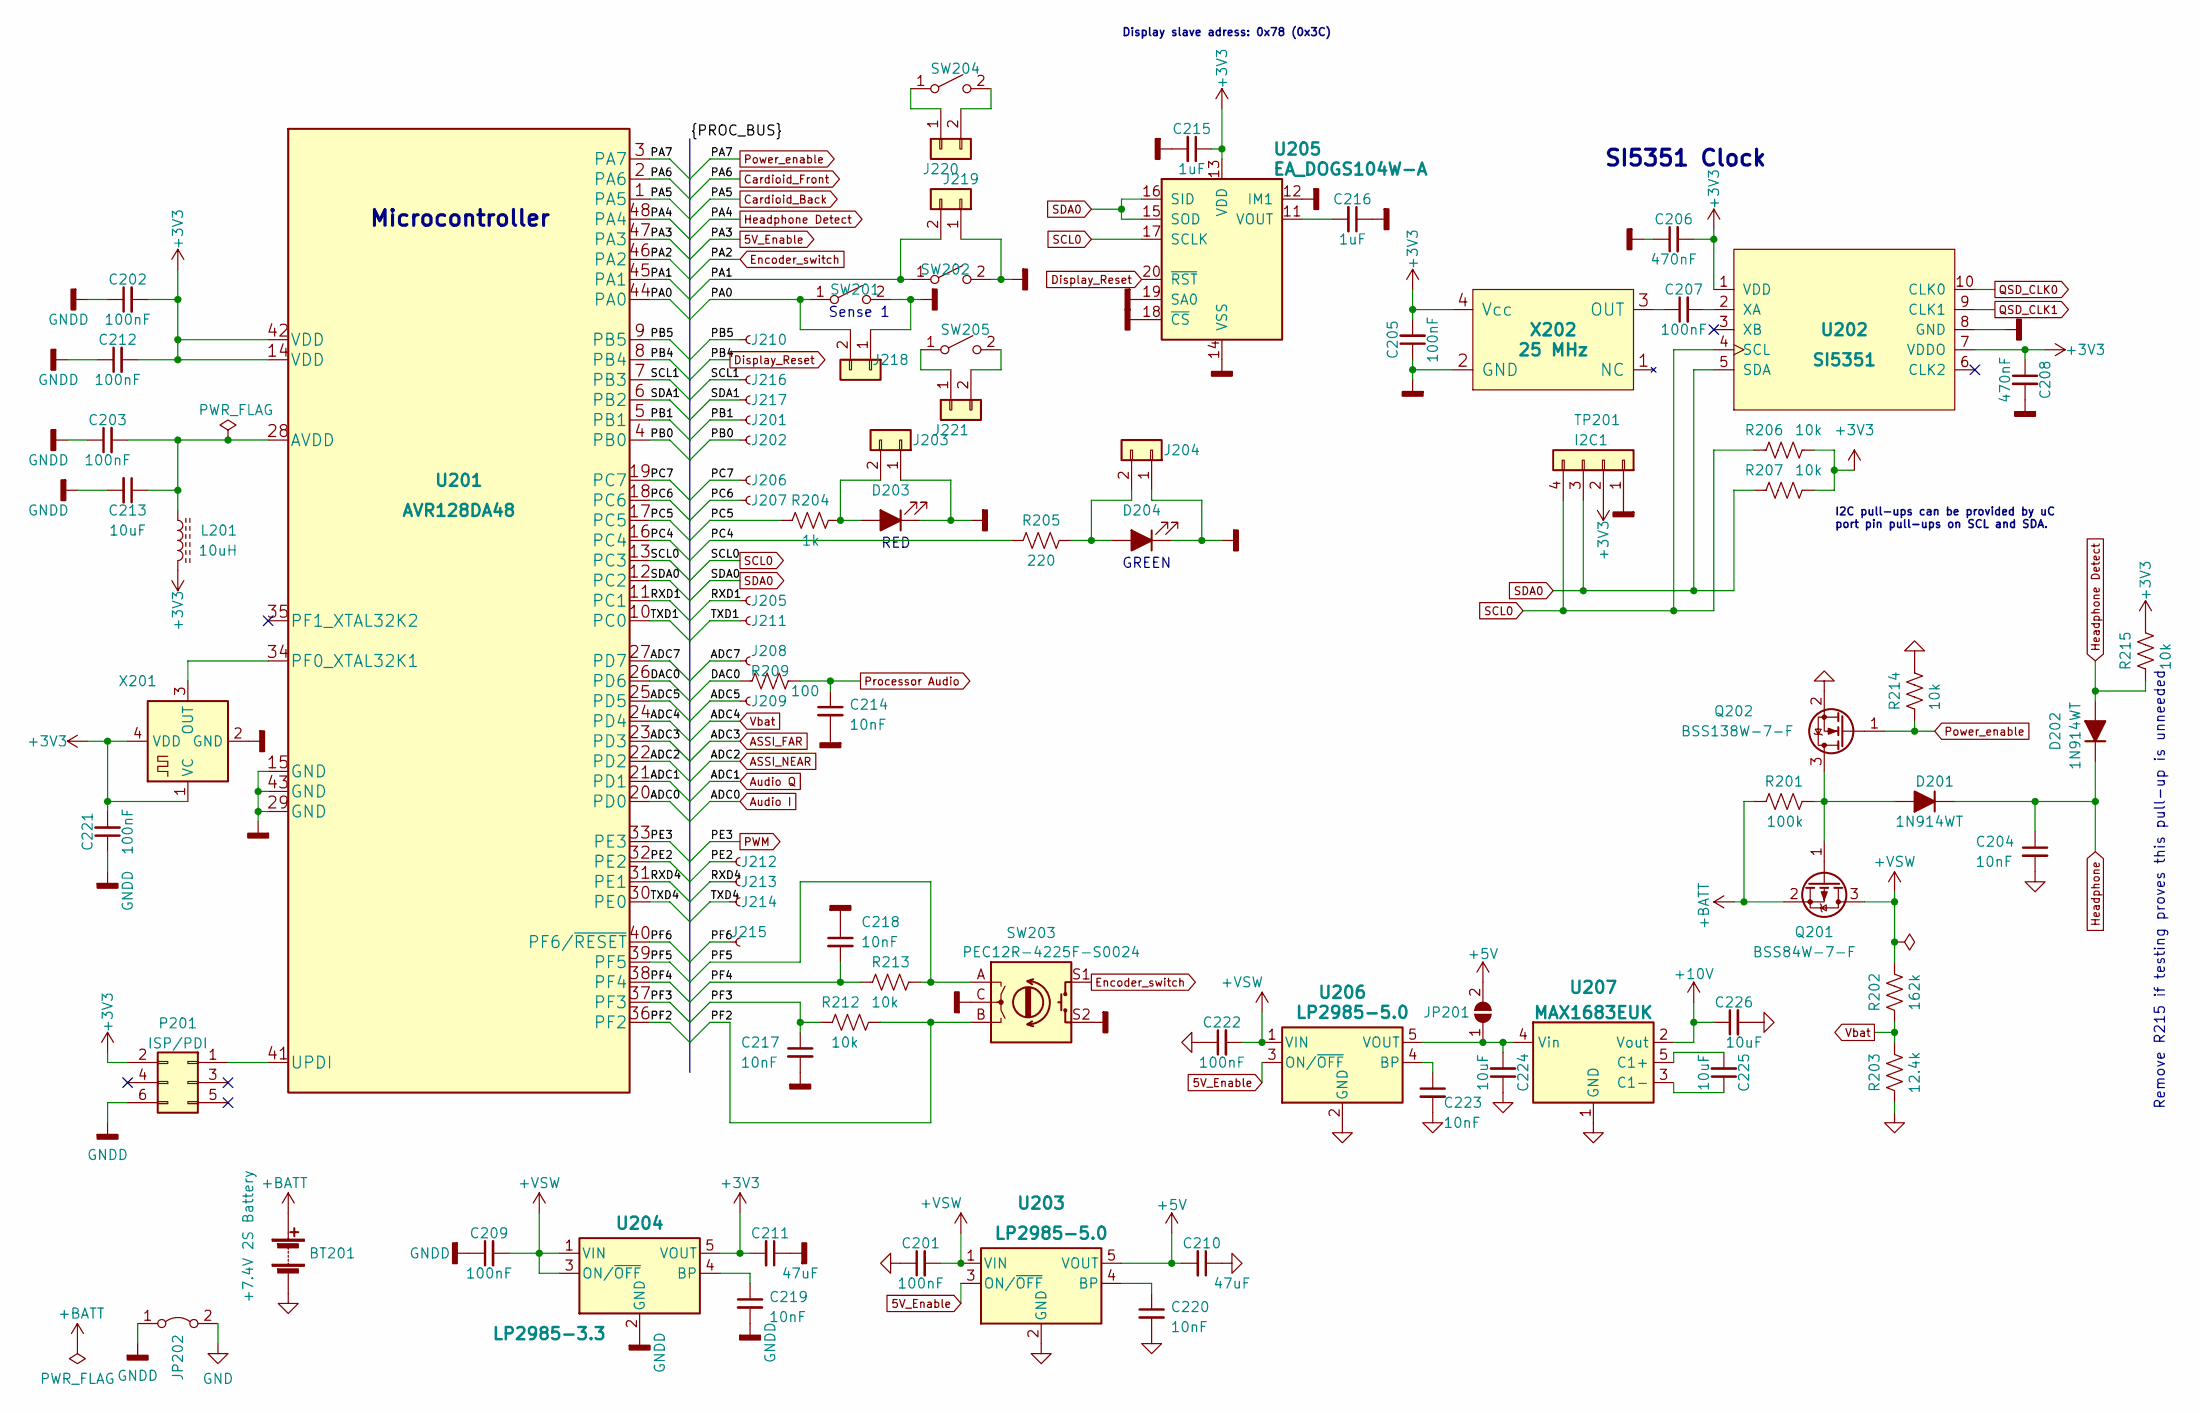
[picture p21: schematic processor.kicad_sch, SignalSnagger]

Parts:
BT201: +7.4V 2S Battery; SolderWire-1sqmm_1x02_P7.8mm_D1.4mm_OD3.9mm_Relief; Digi-Key Part No. NP
C201, C202, C203, C205, C207, C209, C212, C221, C222: 100nF; C_0603_1608Metric; Manufacturer PN CL10B104KA8NNNC; Digi-Key Part No. 1276-1006-1-ND
C204, C214, C217, C218, C219, C220, C223: 10nF; C_0603_1608Metric; Manufacturer PN C0603X103J4HACAUTO; Digi-Key Part No. 399-C0603X103J4HACAUTOCT-ND
C206, C208: 470nF; C_0603_1608Metric; Manufacturer PN CL10B474KA8VPJC; Digi-Key Part No. 1276-CL10B474KA8VPJCCT-ND
C210, C211: 47uF; C_1210_3225Metric; Manufacturer PN CL32A476KOJNNNE; Digi-Key Part No. 1276-3376-1-ND
C213, C224, C225, C226: 10uF; C_0603_1608Metric; Manufacturer PN GRM188C81C106MA73D; Digi-Key Part No. 490-7198-1-ND
C215, C216: 1uF; C_0603_1608Metric; Manufacturer PN CC0603KRX5R8BB105; Digi-Key Part No. 311-1445-1-ND
D201, D202: 1N914WT; D_SOD-523; Manufacturer PN 1N4148WT-7; Digi-Key Part No. 1N4148WTDICT-ND
D203: Red LED; LED_0805_2012Metric; Manufacturer PN LTST-C170KRKT; Digi-Key Part No. 160-1415-1-ND
D204: Green LED; LED_0805_2012Metric; Manufacturer PN LTST-C170KGKT; Digi-Key Part No. 160-1414-1-ND
J201, J202, J205, J206, J207, J208, J209, J210, J211, J212, J213, J214, J215, J216, J217: Conn_01x01_Female; Dummy_Empty
J203, J204, J218, J219, J220, J221: Conn_01x02; PinSocket_1x02_P1.27mm_Vertical; Digi-Key Part No. N/P
JP201: SolderJumper_2_Open; SolderJumper-2_P1.3mm_Open_RoundedPad1.0x1.5mm; Digi-Key Part No. N/P
JP202: Jumper_2_Bridged; Jumper_THT-1x02_Bridged_Circular; Digi-Key Part No. N/P
L201: 10uH; L_0603_1608Metric; Manufacturer PN LQM18DN100M70L; Digi-Key Part No. 490-LQM18DN100M70LCT-ND
P201: ISP/PDI; PinHeader_2x03_P2.54mm_Vertical_SMD; Manufacturer PN 35RASMT2BHSNTRX; Digi-Key Part No. 137-35RASMT2BHSNTRXCT-ND
Q201: BSS84W-7-F; SOT-323_SC-70; Manufacturer PN BSS84W-7-F; Digi-Key Part No. BSS84W-FDICT-ND
Q202: BSS138W-7-F; SOT-323_SC-70; Manufacturer PN BSS138W-7-F; Digi-Key Part No. BSS138W-FDICT-ND
R201: 100k; R_0603_1608Metric; Manufacturer PN RC0603FR-07100KL; Digi-Key Part No. 311-100KHRCT-ND
R202: 162k; R_0603_1608Metric; Manufacturer PN RC0603FR-07162KL; Digi-Key Part No. 311-162KHRCT-ND
R203: 12.4k; R_0603_1608Metric; Manufacturer PN RC0603FR-0712K4L; Digi-Key Part No. 311-12.4KHRCT-ND
R204: 1k; R_0603_1608Metric; Manufacturer PN RC0603FR-071KL; Digi-Key Part No. 311-1.00KHRCT-ND
R205: 220; R_0603_1608Metric; Manufacturer PN RC0603FR-07220RL; Digi-Key Part No. 311-220HRCT-ND
R206, R207, R212, R213, R214, R215: 10k; R_0603_1608Metric; Manufacturer PN RC0603FR-0710KL; Digi-Key Part No. 311-10.0KHRCT-ND
R209: 100; R_0603_1608Metric; Manufacturer PN RC0603FR-07100RL; Digi-Key Part No. 311-100HRCT-ND
SW201, SW202, SW204, SW205: SW_SPST; SW_SPST_TL1014BF160QG; Manufacturer PN TL1014BF160QG; Digi-Key Part No. EG5042CT-ND
SW203: PEC12R-4225F-S0024; RotaryEncoder_Bourns_PEC12R-Switch_Vertical_CircularMountin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; Manufacturer PN PEC12R-4225F-S0024; Digi-Key Part No. PEC12R-4225F-S0024-ND
TP201: I2C1; PinSocket_1x04_P1.27mm_Vertical; Digi-Key Part No. N/P
U201: AVR128DA48; TQFP-48_7x7mm_P0.5mm; Manufacturer PN AVR128DA48T-E/PT; Digi-Key Part No. 150-AVR128DA48T-E/PTCT-ND
U202: SI5351; MSOP-10_3x3mm_P0.5mm; Manufacturer PN SI5351A-B-GT; Digi-Key Part No. 336-2399-5-ND
U203, U206: LP2985-5.0; SOT-23-5; Manufacturer PN LP2985-50DBVR; Digi-Key Part No. 296-20717-1-ND
U204: LP2985-3.3; SOT-23-5; Manufacturer PN LP2985-50DBVR; Digi-Key Part No. 296-20717-1-ND
U205: EA_DOGS104W-A; EA_DOGS104X-A; Manufacturer PN EA DOGS104W-A; Digi-Key Part No. 1481-1233-ND
U207: MAX1683EUK; SOT-23-5; Manufacturer PN MAX1683EUK+T; Digi-Key Part No. MAX1683EUK+TCT-ND
X201: ECS-327TXO-30-TR; Oscillator_SMD_ECS_327TXO; Manufacturer PN ECS-327TXO-30-TR; Digi-Key Part No. 50-ECS-327TXO-30-CT-ND
X202: 25 MHz; Crystal_SMD_TXETCLSANF-4Pin; Manufacturer PN TXETCLSANF-25.000000; Digi-Key Part No. 1664-1273-1-ND

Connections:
5V_Enable: U201.47 (PA3), U203.3 (ON/~OFF), U206.3 (ON/~OFF)
+3V3: C202.2, C205.2, C206.2, C208.1, C211.2, C212.2, C215.1, C221.2, L201.1, P201.2, R206.1, R207.1, R215.1, TP201.2, U201.14 (VDD), U201.42 (VDD), U202.1 (VDD), U202.7 (VDDO), U204.5 (VOUT), U205.13 (VDD), X201.1 (VC), X201.4 (VDD), X202.4 (Vcc)
+5V: C210.2, JP201.2 (B), U203.5 (VOUT); also elsewhere on the board
+10V: C226.1, U207.2 (Vout); also elsewhere on the board
+BATT: BT201.2 (+), Q201.2 (S), R201.1
+VSW: C201.2, C209.2, C222.2, Q201.3 (D), R202.2, U203.1 (VIN), U204.1 (VIN), U204.3 (ON/~OFF), U206.1 (VIN); also elsewhere on the board
/Processor/ADC5: J209.1, U201.25 (PD5)
/Processor/ADC7: J208.1, U201.27 (PD7)
/Processor/DAC0: R209.1, U201.26 (PD6)
/Processor/PA0: J218.2, SW201.1 (A), U201.44 (PA0)
/Processor/PA1: J219.2, SW202.1 (A), U201.45 (PA1)
/Processor/PB0: J202.1, U201.4 (PB0)
/Processor/PB1: J201.1, U201.5 (PB1)
/Processor/PB5: J210.1, U201.9 (PB5)
/Processor/PC4: R205.1, U201.16 (PC4)
/Processor/PC5: R204.1, U201.17 (PC5)
/Processor/PC6: J207.1, U201.18 (PC6)
/Processor/PC7: J206.1, U201.19 (PC7)
/Processor/PE2: J212.1, U201.32 (PE2)
/Processor/PF2: R212.1, SW203.B, U201.36 (PF2)
/Processor/PF3: C217.1, R212.2, U201.37 (PF3)
/Processor/PF4: C218.2, R213.2, U201.38 (PF4)
/Processor/PF5: R213.1, SW203.A, U201.39 (PF5)
/Processor/PF6: J215.1, U201.40 (PF6/~RESET)
/Processor/RXD1: J205.1, U201.11 (PC1)
/Processor/RXD4: J213.1, U201.31 (PE1)
/Processor/SCL1: J216.1, U201.7 (PB3)
/Processor/SDA1: J217.1, U201.6 (PB2)
/Processor/TXD1: J211.1, U201.10 (PC0)
/Processor/TXD4: J214.1, U201.30 (PE0)
ASSI_FAR: U201.23 (PD3)
ASSI_NEAR: U201.22 (PD2); also elsewhere on the board
Audio I: U201.20 (PD0); also elsewhere on the board
Audio Q: U201.21 (PD1); also elsewhere on the board
Cardioid_Back: U201.1 (PA5); also elsewhere on the board
Cardioid_Front: U201.2 (PA6); also elsewhere on the board
Display_Reset: U201.8 (PB4), U205.20 (~RST)
Encoder_switch: SW203.S1, U201.46 (PA2)
GND: BT201.1 (-), C201.1, C204.2, C210.1, C220.2, C222.1, C223.2, C224.1, C226.2, JP202.2 (B), Q202.2 (S), R203.1, R214.1, U203.2 (GND), U206.2 (GND), U207.1 (GND); also elsewhere on the board
GNDD: C202.1, C203.1, C205.1, C206.1, C208.2, C209.1, C211.1, C212.1, C213.2, C214.2, C215.2, C216.1, C217.2, C218.1, C219.2, C221.1, D203.1 (K), D204.1 (K), J203.1, J204.1, J218.1, J219.1, JP202.1 (A), P201.6, SW201.2 (B), SW202.2 (B), SW203.C, SW203.S2, TP201.1, U201.15 (GND), U201.29 (GND), U201.43 (GND), U202.8 (GND), U204.2 (GND), U205.12 (IM1), U205.14 (VSS), U205.18 (~CS), U205.19 (SA0), X201.2 (GND), X202.2 (GND)
Headphone: C204.1, D201.1 (K), D202.1 (K); also elsewhere on the board
Headphone Detect: D202.2 (A), R215.2, U201.48 (PA4)
unnamed: C203.2, C213.1, L201.2, U201.28 (AVDD)
unnamed: C207.1, X202.3 (OUT)
unnamed: C207.2, U202.2 (XA)
unnamed: C216.2, U205.11 (VOUT)
unnamed: C219.1, U204.4 (BP)
unnamed: C220.1, U203.4 (BP)
unnamed: C223.1, U206.4 (BP)
unnamed: C224.2, JP201.1 (A), U206.5 (VOUT), U207.4 (Vin)
unnamed: C225.1, U207.3 (C1-)
unnamed: C225.2, U207.5 (C1+)
unnamed: D201.2 (A), Q201.1 (G), Q202.3 (D), R201.2
unnamed: D203.2 (A), J203.2, R204.2
unnamed: D204.2 (A), J204.2, R205.2
unnamed: J220.1, SW204.1 (A)
unnamed: J220.2, SW204.2 (B)
unnamed: J221.1, SW205.1 (A)
unnamed: J221.2, SW205.2 (B)
unnamed: P201.1, U201.41 (UPDI)
unnamed: U201.34 (PF0_XTAL32K1), X201.3 (OUT)
PWM: U201.33 (PE3); also elsewhere on the board
Power_enable: Q202.1 (G), R214.2, U201.3 (PA7)
Processor Audio: C214.1, R209.2; also elsewhere on the board
QSD_CLK0: U202.10 (CLK0); also elsewhere on the board
QSD_CLK1: U202.9 (CLK1); also elsewhere on the board
SCL0: R206.2, TP201.4, U201.13 (PC3), U202.4 (SCL), U205.17 (SCLK)
SDA0: R207.2, TP201.3, U201.12 (PC2), U202.5 (SDA), U205.15 (SOD), U205.16 (SID)
Vbat: R202.1, R203.2, U201.24 (PD4)

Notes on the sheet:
Remove R215 if testing proves this pull-up is unneeded
I2C pull-ups can be provided by uC port pin pull-ups on SCL and SDA.
GREEN
Display slave adress: 0x78 (0x3C)
Sense 1
RED
Microcontroller
SI5351 Clock

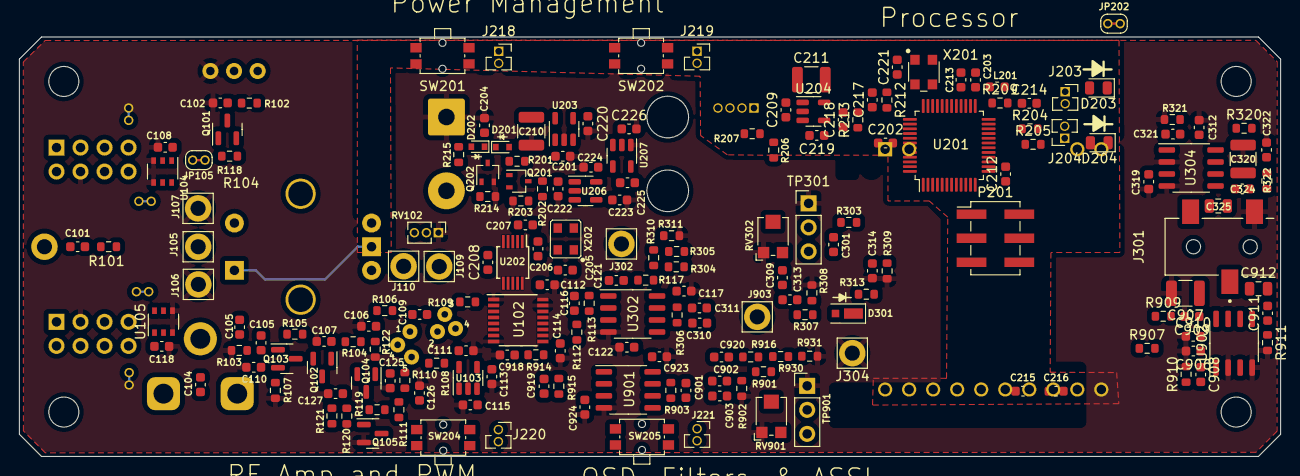
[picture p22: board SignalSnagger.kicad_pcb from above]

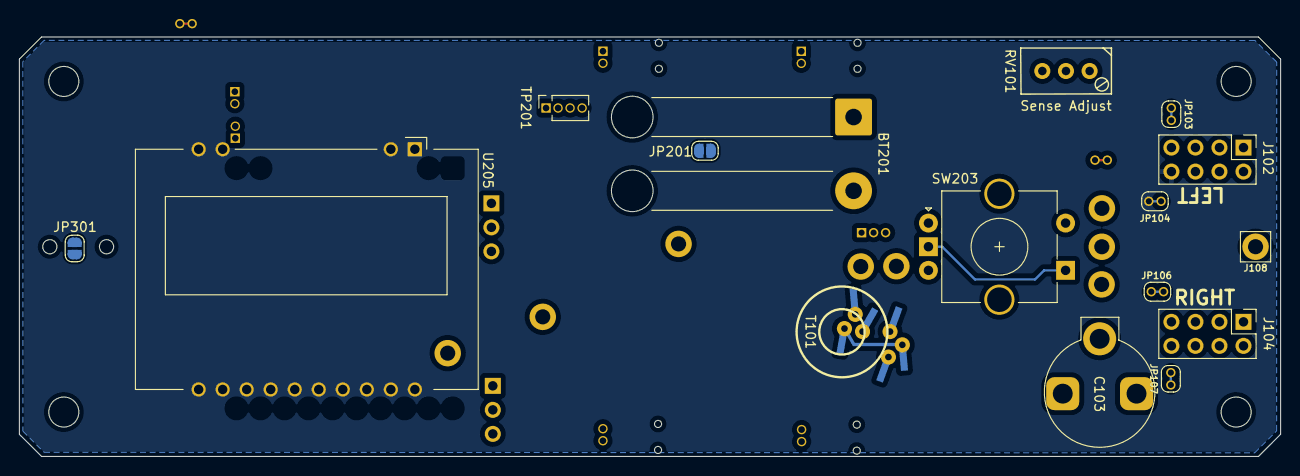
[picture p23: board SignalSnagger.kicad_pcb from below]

Board: 4 copper layers, 133.4 x 44.3 mm, 205 parts (15 on the bottom side), 126 nets.

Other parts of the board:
C105#2: 10nF; C_0603_1608Metric

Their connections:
unnamed 60: C105#2.1; also elsewhere on the board
unnamed 65: C105#2.2; also elsewhere on the board

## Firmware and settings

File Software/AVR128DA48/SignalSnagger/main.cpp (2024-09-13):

#include "atmel_start.h"
#include <avr/io.h>
#include <avr/interrupt.h>
#include <string.h>
#include <time.h>
#include <stdio.h>
#include <ctype.h>
#include <avr/sleep.h>
#include <atomic.h>
#include <math.h>

#include "receiver.h"
#include "morse.h"
#include "adc.h"
#include "Goertzel.h"
#include "util.h"
#include "binio.h"
#include "eeprommanager.h"
#include "binio.h"
#include "leds.h"
#include "CircularStringBuff.h"
#include "CircularFloatBuff.h"
#include "CircularUintBuff.h"
#include "rtc.h"
#include "tca.h"
#include "display.h"
#include "dac0.h"

#include <cpuint.h>
#include <ccp.h>
#include <atomic.h>


/***********************************************************************
 * Local Typedefs
 ************************************************************************/

enum WDReset
{
	WD_SW_RESETS,
	WD_HW_RESETS,
	WD_FORCE_RESET,
	WD_DISABLE
};

enum Awakened_t
{
	AWAKENED_INIT,
	POWER_UP_START,
	AWAKENED_BY_CLOCK,
	AWAKENED_BY_ANTENNA,
	AWAKENED_BY_BUTTONPRESS
};

enum HardwareError_t
{
	HARDWARE_OK,
	HARDWARE_NO_RTC = 0x01,
	HARDWARE_NO_SI5351 = 0x02,
	HARDWARE_NO_WIFI = 0x04,
	HARDWARE_NO_12V = 0x08,
	HARDWARE_NO_FET_BIAS = 0x10
};


enum MenuState_t {
	MenuOperational,
	MenuFreqMemories,
	MenuSetMemFreq,
	MenuSetMemName,
	MenuMain,
	MenuBattery,
	MenuSetmAh,
	MenuSetBatThresh,
	MenuClock,
	MenuAbout,
	MenuInactivityPoweroff,
	MenuNoHeadphones,
	NumberOfMenuStates,
	MenuBackOne,
	MenuGetCurrent
	};
	
enum SwitchAction_t {
	SwitchClosure,
	SwitchRelease,
	SwitchUnchanged
	};

enum PrimaryMenu_t {
	MEMORIES,
	BATTERY,
	CLOCK,
	EVENTS,
	SOUNDS,
	SETTINGS,
	ABOUT, /* Product Name, SW Version, HW Version? */
	NUMBER_OF_MENUS,
	INVALID_MENU
	};

// #define NUMBER_OF_MENUS 5
const char menuTitle[NUMBER_OF_MENUS][10] = {"MEMORIES", "BATTERY", "CLOCK", "EVENT", "SOUNDS", "SETTINGS", "ABOUT"};
// #define MEMORIES 0
// #define BATTERY 1
#define EMPTY_MEMORY 0
#define INVALID_CHANNEL 0xFF
#define INVALID_FREQUENCY 0
#define MEMORY_DEFAULT_FREQUENCY 3550000
const char clearRow[11] = "          ";

const char channelNames[NUMBER_OF_FREQUENCY_CHANNEL_NAMES][7] = {"???", "FOXES ", "BEACON", "SPEC  ", "SLOW  ", "FAST  ", "FOX-1 ", "FOX-1F", "FOX-2 ", "FOX-2F", "FOX-3 ", "FOX-3F", "FOX-4 ", "FOX-4F", "FOX-5 ", "FOX-5F", "FOX-6 ", "FOX-6F", "FOX   ", "FINISH", "START ", "LOW   ", "MID   ", "HIGH  "};
uint8_t g_channel_name[NUMBER_OF_FREQUENCY_CHANNELS] = {};

#define QUAD_MASK ((1 << ROTARY_A_IN) | (ROTARY_B_IN))

/***********************************************************************
 * Global Variables & String Constants
 *
 * Identify each global with a "g_" prefix
 * Whenever possible limit globals' scope to this file using "static"
 * Use "volatile" for globals shared between ISRs and foreground
 ************************************************************************/

#define TEMPSTR_SIZE 100
static char g_tempStr[TEMPSTR_SIZE] = { '\0' };

static volatile bool g_battery_measurements_active = false;
static volatile uint16_t g_maximum_battery = 0;

static volatile uint16_t g_powerdown_seconds = INACTIVITY_POWER_DOWN_DELAY_SECONDS;
static volatile bool g_headphones_detected = false;
static volatile bool g_powering_off = false;

static volatile int g_sendID_seconds_countdown = 0;
static volatile uint16_t g_code_throttle = 50;
static volatile uint16_t g_enunciation_code_throttle = 50;
static volatile uint8_t g_WiFi_shutdown_seconds = 120;
static volatile uint16_t g_hardware_error = (uint16_t)HARDWARE_OK;

static volatile bool g_rotary_enable = false;
static volatile int g_rotary_count = 0;
static volatile int g_rotary_edges = 0;
#define ROTARY_SYNC_DELAY 75

static uint8_t g_rf_gain_setting = MAX_PWM_SETTING/2;

extern volatile Frequency_Hz g_rx_frequency;
extern volatile Frequency_Hz g_frequency_low;
extern volatile Frequency_Hz g_frequency_med;
extern volatile Frequency_Hz g_frequency_hi;
extern volatile Frequency_Hz g_frequency_beacon;
extern Frequency_Hz g_channel_frequency[NUMBER_OF_FREQUENCY_CHANNELS];
extern FrequencyMode_t g_frequency_mode;
extern volatile BatteryCapacity_t g_battery_capacity;
extern volatile BatteryWarnThreshold_t g_battery_warning_threshold;
extern volatile uint8_t g_active_memory;

volatile bool g_seconds_transition = false;
volatile time_t g_seconds_since_poweron = 0;
volatile uint8_t g_display_active_countdown = false;

static volatile bool g_sufficient_power_detected = false;
static volatile bool g_enableHardwareWDResets = false;
extern uint16_t g_clock_calibration;

static volatile bool g_go_to_sleep_now = false;
static volatile bool g_sleeping = false;
static volatile time_t g_time_to_wake_up = 0;
static volatile Awakened_t g_awakenedBy = POWER_UP_START;
static volatile SleepType g_sleepType = SLEEP_FOREVER;

#define NUMBER_OF_POLLED_ADC_CHANNELS 1
#define TOTAL_OF_ALL_ADC_CHANNELS 8
static const uint16_t g_adcChannelConversionPeriod_ticks[NUMBER_OF_POLLED_ADC_CHANNELS] = { 3000 };
static volatile uint16_t g_adcCountdownCount[NUMBER_OF_POLLED_ADC_CHANNELS] = { 3000 };
static volatile bool g_adcUpdated[NUMBER_OF_POLLED_ADC_CHANNELS] = { false };
static volatile int16_t g_adcChannel2Slot[TOTAL_OF_ALL_ADC_CHANNELS] = { -1, -1, -1, -1, -1, -1, -1, 0 };
static volatile uint16_t g_lastConversionResult[NUMBER_OF_POLLED_ADC_CHANNELS] = { 0 };
static volatile ADC_Active_Channel_t g_active_ADC_sample = ADC_I_AMPED;

extern Goertzel g_goertzel;
uint16_t g_goertzel_rssi = 0;

static volatile uint16_t g_leftsense_closed_time = 0;
static volatile uint16_t g_rightsense_closed_time = 0;
static volatile uint16_t g_encoder_closed_time = 0;
static volatile uint16_t g_doublesense_closed_time = 0;

static volatile uint16_t g_handle_counted_leftsense_presses = 0;
static volatile uint16_t g_handle_counted_rightsense_presses = 0;
static volatile uint16_t g_handle_counted_encoder_presses = 0;
static volatile uint16_t g_handle_counted_doublesense_presses = 0;

static volatile uint16_t g_leftsense_presses_count = 0;
static volatile uint16_t g_rightsense_presses_count = 0;
static volatile uint16_t g_encoder_presses_count = 0;
static volatile uint16_t g_doublesense_presses_count = 0;

static volatile bool g_long_leftsense_press = false;
static volatile bool g_long_rightsense_press = false;
static volatile bool g_long_doublesense_press = false;
static volatile bool g_long_encoder_press = false;

static volatile bool g_leftsense_pressed = false;
static volatile bool g_rightsense_pressed = false;
static volatile bool g_doublesense_pressed = false;
static volatile bool g_encoderswitch_pressed = false;

volatile uint16_t g_audio_gain = 4;
volatile bool g_enable_audio_feedthrough = true;

volatile uint16_t g_check_temperature = 0;

Enunciation_t g_enunciator = LED_ONLY;

Display display = Display();
leds LEDS = leds();
CircularStringBuff g_text_buff = CircularStringBuff(TEXT_BUFF_SIZE);

#define NOMINAL_BUFF_SIZE 30
#define HIGH_WATER_BUFF_SIZE 10
static CircularFloatBuff g_nominal_buff = CircularFloatBuff(NOMINAL_BUFF_SIZE);
static CircularFloatBuff g_high_water_buff = CircularFloatBuff(HIGH_WATER_BUFF_SIZE);
static CircularUintBuff g_rssi_buff = CircularUintBuff(HIGH_WATER_BUFF_SIZE);

EepromManager EEPromMgr;

#define Goertzel_N 209
#define SAMPLE_RATE 96154 /* 480965 12080  13868 */
const int N = Goertzel_N;
//const float threshold = 500000. * (Goertzel_N / 100);
const float sampling_freq = SAMPLE_RATE;
const float pitch_frequencies[3] = { 600., 700., 800.}; /* should be an integer multiple of SAMPLING_RATE/N (SAMPLE_RATE / Goertzel_N) */
volatile uint16_t g_rssi_countdown = 100;

volatile bool g_audio_test = false;

/* VREF start-up time */
#define VREF_STARTUP_TIME       (50)
/* Mask needed to get the 2 LSb for DAC Data Register */
#define LSB_MASK                (0x03)
/* Number of samples for a sine wave period */
#define SINE_PERIOD_STEPS       (25)
#define MAX_SINE_PERIOD_STEPS   (201)
/* Sine wave amplitude */
#define SINE_AMPLITUDE          (1) // (511)
/* Sine wave DC offset */
#define SINE_DC_OFFSET          (2048) //(512)
/* Frequency of the sine wave */
// #define SINE_FREQ               (200)
// /* Step delay for the loop */
// #define STEP_DELAY_TIME         1./13868.

static void sineWaveInit(int sine_period_steps);

/* Buffer to store the sine wave samples */
uint16_t sineWave[MAX_SINE_PERIOD_STEPS];
static volatile uint8_t g_sine_period_steps = 25;
static volatile uint16_t g_beep = 0;
static volatile uint8_t g_tick = 0;


/***********************************************************************
 * Private Function Prototypes
 *
 * These functions are available only within this file
 ************************************************************************/
void wdt_init(WDReset resetType);
EC hw_init(void);
char* batteryVoltsString(bool volts, float* value);
char* batteryPercentString(float adcCounts, float* result);
char* batteryTimeLeftString(float* adcCounts);

uint8_t nextActiveMemory(uint8_t currentChan, bool up);
MenuState_t setMenu(MenuState_t menu);
// char* centerHorizontally(const char* text, uint8_t row);

int repChar(char *str, char orig, char rep);
char *trimwhitespace(char *str);

/* One-second interrupts */
ISR(RTC_CNT_vect)
{
	uint8_t x = RTC.INTFLAGS;
	
    if (x & RTC_OVF_bm )
    {
        system_tick();
		if(g_powerdown_seconds) g_powerdown_seconds--;
		g_seconds_transition = true;
		g_seconds_since_poweron++;
		if(g_seconds_since_poweron == 2) g_rotary_enable = true;
		if(g_display_active_countdown) g_display_active_countdown--;
	}
 
    RTC.INTFLAGS = (RTC_OVF_bm | RTC_CMP_bm);
}

/* ADC sampling timer interrupt */
// ISR(TCA1_OVF_vect)
// {
// 	if(x & TCA_SINGLE_OVF_bm)
// 	{
// 	}
// 
// 	TCA1.SINGLE.INTFLAGS = (TCA_SINGLE_OVF_bm | TCA_SINGLE_CMP0_bm | TCA_SINGLE_CMP1_bm | TCA_SINGLE_CMP2_bm); /* clear all interrupt flags */
// }


/** 
ADC Result Ready Interrupt
*/
ISR(ADC0_RESRDY_vect)
{
	uint8_t x = ADC0.INTFLAGS;
	
	if(x & ADC_RESRDY_bm)
	{
// 		static uint8_t indexSingleConversionInProcess = NO_ADC_SELECTED;
		static uint8_t sineIndex = 0;
		uint16_t sample = ADC0.RES;
		uint16_t result = 0;
// 		bool passAudio = true;

		if(g_enable_audio_feedthrough)
		{
			result = sample;
		}
				
// 		if(g_active_ADC_sample != ADC_I_AMPED)
// 		{			
// 			if(indexSingleConversionInProcess == NO_ADC_SELECTED) /* set up to take a single sample of another channel */
// 			{
// 				ADC0.MUXPOS = indexSingleConversionInProcess;
// 				indexSingleConversionInProcess = g_active_ADC_sample;
// 				ADC0.CTRLC = ADC_PRESC_DIV2_gc;
// 				ADC0.CTRLA = ADC_ENABLE_bm /* ADC Enable: enabled */
// 					| ADC_RESSEL_12BIT_gc      /* 12-bit mode */
// 					| ADC_FREERUN_bm;          /* Enable Free-Run mode */
// 			}
// 			else /* read result of a single sample of another channel */
// 			{
// 					int16_t slot = g_adcChannel2Slot[indexSingleConversionInProcess];
// 					g_lastConversionResult[slot] = result;
// 					g_adcUpdated[slot] = true;
// 					ADC0.MUXPOS = ADC_I_AMPED;
// 					g_active_ADC_sample = ADC_I_AMPED;
// 					ADC0.CTRLC = ADC_PRESC_DIV128_gc;
// 					ADC0.CTRLA = ADC_ENABLE_bm /* ADC Enable: enabled */
// 					| ADC_RESSEL_10BIT_gc      /* 10-bit mode */
// 					| ADC_FREERUN_bm;          /* Enable Free-Run mode */
//					indexSingleConversionInProcess = NO_ADC_SELECTED;
// 					passAudio = false;
// 			}
// 		}
		
 		if(g_audio_test)
		{
			if(g_sine_period_steps)
			{
				if(g_beep)
				{
					result += sineWave[sineIndex++];
					if(sineIndex == g_sine_period_steps) sineIndex = 0;
					g_beep--;
				}
				DAC0_setVal(result);
				g_goertzel.DataPoint(result);
			}
		}
		else
		{
			if(g_beep)
			{
				result += sineWave[sineIndex++];
				if(sineIndex == g_sine_period_steps) sineIndex = 0;
				g_beep--;
			}
			else if(g_tick)
			{
				g_tick--;
				result = 0;
			}
		
			if(g_audio_gain > 4)
			{
				result = result << (g_audio_gain - 4);
			}
			else
			{
				result = result >> (4 - g_audio_gain);
			}
		
			DAC0_setVal(result);
			g_goertzel.DataPoint(sample);
// 				PORTC_toggle_pin_level(5);
		}
	}
	
	ADC0.INTFLAGS = (ADC_RESRDY_bm | ADC_WCMP_bm);
}
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
int main(void)
{
	sineWaveInit(25);
	
	MenuState_t hold_menuState = MenuOperational;
	bool frequency_updates_enabled = false;
	uint8_t hold_activeMemory = 0;
	Frequency_Hz hold_activeMemoryFreq = 0;
	
	PrimaryMenu_t hold_menuRow = MEMORIES;
	PrimaryMenu_t menuRow = MEMORIES;

	Frequency_Hz hold_rx_frequency = 0;
	uint8_t hold_rf_gain_setting = 255;
//	uint16_t hold_assi_result = 0;
	uint16_t hold_audio_gain = 0;
	uint16_t hold_goertzel_rssi = 0;
	bool hold_headphone_state = true;
	bool refresh_display = true;
	uint8_t x;
	EC ec;
	bool inhibit_long_encoder_press = false;
	
	float temp_float = 0.;
		
	atmel_start_init();

	x = si5351_get_status() & 0x80;
	while((util_delay_ms(1000)) && x)
	{
		x = si5351_get_status() & 0x80;
	}
	
	EEPromMgr.initializeEEPROMVars();
	EEPromMgr.readNonVols();

	ec = init_receiver(g_rx_frequency);
	
	if(ec != ERROR_CODE_NO_ERROR)
	{
		g_hardware_error |= (int)HARDWARE_NO_SI5351;
	}
		
	RTC_set_calibration(g_clock_calibration);
					
	/* Check that the RTC is running */
	set_system_time(YEAR_2000_EPOCH);
	time_t now = time(null);
 	while((util_delay_ms(2000)) && (now == time(null)));
	
	if(now == time(null))
	{
		g_hardware_error |= (int)HARDWARE_NO_RTC;
 		RTC_init_backup();
	}
	
	display.begin(DOGS104);
	
	if(g_hardware_error)
	{
 		LEDS.blink(LEDS_RED_AND_GREEN_BLINK_FAST, true);

		g_text_buff.putString((char*)"00Error:");
		if(g_hardware_error & (int)HARDWARE_NO_SI5351)
		{
			g_text_buff.putString((char*)"11SI5351");
		}
		
		if(g_hardware_error & (int)HARDWARE_NO_RTC)
		{
			g_text_buff.putString((char*)"2132kCLK");
		}
		
		g_display_active_countdown = 15;
	}
	else
	{
		float percent;
		ADC0.MUXPOS = ADCBatteryVoltage;
		uint16_t result = 0;		
		ADC0_SYSTEM_init(ADC12BIT, false);
		
		for(int i=0; i<10; i++)
		{
			ADC0_startConversion();
			while(!ADC0_conversionDone());
			result = ADC0.RES;
			temp_float += result;
		}
		
		temp_float /= 10;
		batteryPercentString(temp_float, &percent);
		
		if(percent <= (float)g_battery_warning_threshold)
		{
			g_text_buff.putString((char*)"00BATTERY\0");
			g_text_buff.putString((char*)"10  WARNING!\0");
			snprintf(g_tempStr, 13, "20%s Volts", batteryVoltsString(true, &temp_float));
			g_text_buff.putString(g_tempStr);
			snprintf(g_tempStr, 13, "30min: %s  ", batteryTimeLeftString(&temp_float));
			g_beep = 5000;
			g_display_active_countdown = 30;
		}
		else
		{
			g_display_active_countdown = 0;
		}
	}
	
	LEDS.blink(LEDS_OFF);
	g_text_buff.putString((char*)g_tempStr);
	
	/* Start audio flow */
	ADC0.MUXPOS = ADC_I_AMPED; 
	ADC0_SYSTEM_init(ADC12BIT, true);
 	ADC0_startConversion();

	while (1) 
	{
		if(!g_display_active_countdown)
		{
			MenuState_t currentMenu = setMenu(MenuGetCurrent);
			
			if(refresh_display || (currentMenu != hold_menuState))
			{
				refresh_display = false;
				
				if((hold_menuState == MenuBattery) || (hold_menuState == MenuSetmAh) || (hold_menuState == MenuSetBatThresh))
				{
					if((currentMenu != MenuBattery) && (currentMenu != MenuSetmAh) && (currentMenu != MenuSetBatThresh))
					{
						ADC0.MUXPOS = ADC_I_AMPED; 
						ADC0_SYSTEM_init(ADC12BIT, true);
 						ADC0_startConversion();
					}
				}
				
				hold_menuState = currentMenu;
				display.cls();
				hold_rx_frequency = 0; /* force update */
				hold_rf_gain_setting = 0xff; /* force update */
				hold_audio_gain = 0xff; /* force update */
				hold_activeMemory = 0xff; /* force update */
				hold_goertzel_rssi = 0; /* force update */
				hold_menuRow = INVALID_MENU; /* force update */
				
				if(currentMenu == MenuOperational)
				{
					EEPromMgr.saveAllEEPROM();					
					display.display(LINES_4);						
				}
				else if(currentMenu == MenuNoHeadphones)
				{
					display.display(LINES_2);
				}
			}
			
			switch(currentMenu)
			{
				case MenuOperational:
				{
					char str[11];
					if(g_frequency_mode == MODE_VFO)
					{	
						if(hold_rx_frequency != g_rx_frequency)
						{
							hold_rx_frequency = g_rx_frequency;
				
							frequencyString(str, hold_rx_frequency);
							sprintf(g_tempStr, "00VFO%s%s", frequency_updates_enabled ? ">":" ", str);
							g_text_buff.putString(g_tempStr);
						}
					}
					else
					{
						if(hold_activeMemory != g_active_memory)
						{
							hold_activeMemory = g_active_memory;
							hold_rx_frequency = g_rx_frequency;
						
							if(g_channel_name[g_active_memory])
							{
								snprintf(g_tempStr, 13, "00M%02d%s%s", hold_activeMemory + 1, frequency_updates_enabled ? ">":" ", channelNames[g_channel_name[g_active_memory]]);
							}
							else
							{
								frequencyString(str, hold_rx_frequency);
								snprintf(g_tempStr, 13, "00M%02d%s%s", hold_activeMemory + 1, frequency_updates_enabled ? ">":" ", str);
							}
							
							g_text_buff.putString(g_tempStr);
						}
					}
			
					if(hold_rf_gain_setting != g_rf_gain_setting)
					{
						hold_rf_gain_setting = g_rf_gain_setting;
				
						sprintf(g_tempStr, "10RF=%d  ", MAX_PWM_SETTING - g_rf_gain_setting);
						g_text_buff.putString(g_tempStr);
					}

					if(hold_audio_gain != g_audio_gain)
					{
						hold_audio_gain = g_audio_gain;
						sprintf(g_tempStr, "20A=%d  ", hold_audio_gain);
						g_text_buff.putString(g_tempStr);
					}
			
					if(hold_goertzel_rssi != g_goertzel_rssi)
					{
						hold_goertzel_rssi = g_goertzel_rssi;
						snprintf(g_tempStr, 7, "30%u   ", hold_goertzel_rssi);
						g_text_buff.putString(g_tempStr);
					}
				}
				break;
				
				case MenuMain:
				{
					if(hold_menuRow != menuRow)
					{
						hold_menuRow = menuRow;
						
						display.display(LINES_3_3);						

						sprintf(g_tempStr, "00Main Menu");
						g_text_buff.putString(g_tempStr);
						sprintf(g_tempStr, "20%s", clearRow);
						g_text_buff.putString(g_tempStr);
						sprintf(g_tempStr, "20%s", menuTitle[menuRow]);
						g_text_buff.putString(g_tempStr);
					}									
				}
				break;
				
				case MenuSetBatThresh:
				case MenuSetmAh:
				case MenuBattery:
				{
					uint16_t result = 0;
					static float filtered_float = 0.;
		
						ADC0_startConversion();
						while(!ADC0_conversionDone());
						result = ADC0.RES;
						
						if(filtered_float < 1.)
						{
							filtered_float = (float)result;
						}
						else
						{
							filtered_float = filtered_float * 10. + (float)result;
						}
		
					filtered_float /= 11.;

					snprintf(g_tempStr, 13, "00Bat: %sV", batteryVoltsString(true, &filtered_float));
					g_text_buff.putString(g_tempStr);
					
					if(currentMenu == MenuBattery)
					{
						;
						snprintf(g_tempStr, 13, "20pcnt: %s  ", batteryPercentString(filtered_float, null));
						g_text_buff.putString(g_tempStr);
						snprintf(g_tempStr, 13, "30min: %s  ", batteryTimeLeftString(&filtered_float));
					}
					else if(currentMenu == MenuSetmAh)
					{
						snprintf(g_tempStr, 13, "20> %d mAh  ",  ((uint8_t)g_battery_capacity + 1)*50);						
					}
					else
					{
						snprintf(g_tempStr, 13, "20thre> %d%%  ", g_battery_warning_threshold);
					}
					
					g_text_buff.putString(g_tempStr);
				}
				break;
				
				case MenuSetMemFreq:
				case MenuFreqMemories:
				case MenuSetMemName:
				{
					if(g_active_memory > NUMBER_OF_FREQUENCY_CHANNELS)
					{
						g_active_memory = 0;
					}
					
					Frequency_Hz chanF = g_channel_frequency[g_active_memory];
										
					/* Reset any corrupted memory locations */
					if((chanF > RX_MAXIMUM_80M_FREQUENCY) || (chanF < RX_MINIMUM_80M_FREQUENCY))
					{
						g_channel_frequency[g_active_memory] = 0;
						chanF = 0;
					}
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

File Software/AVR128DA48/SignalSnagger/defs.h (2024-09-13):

/**********************************************************************************************
* Copyright © 2017 Digital Confections LLC
*
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
**********************************************************************************************/

#ifndef DEFS_H
#define DEFS_H

#ifndef F_CPU
 #define F_CPU 24000000UL /* gets declared in makefile */
#endif

#include <avr/io.h>
#include <avr/interrupt.h>
#include <stdint.h>

/******************************************************
 * Set the text that gets displayed to the user       */
#define SW_REVISION "0.38"

//#define TRANQUILIZE_WATCHDOG

#define PRODUCT_NAME_SHORT "SignalSnagger Rx"
#define PRODUCT_NAME_LONG "SignalSnagger 80m ARDF Receiver"

/*******************************************************/

/*******************************************************
 * I2C Slave Addresses                                 */
#define SI5351_I2C_SLAVE_ADDR			0xC0   
#define DISPLAY_I2C_SLAVE_ADDR			0x78
#define DIGITAL_POT_I_I2C_SLAVE_ADDR	0x2F
#define DIGITAL_POT_Q_I2C_SLAVE_ADDR	0x2F
#define RF_GAIN_DAC_I2C_SLAVE_ADDR		0x61
/*******************************************************/

/*******************************************************/
#define INACTIVITY_POWER_DOWN_DELAY_SECONDS 1800
/*******************************************************/

/******************************************************
 * Include only the necessary hardware support */
#define INCLUDE_SI5351_SUPPORT true // Silicon Labs Programmable Clock

#define DATE_STRING_SUPPORT_ENABLED

/*******************************************************/
/* Error Codes                                                                   */
/*******************************************************/
typedef enum {
	ERROR_CODE_NO_ERROR = 0x00,
	ERROR_CODE_REPORT_NO_ERROR = 0x01,
	ERROR_CODE_EVENT_STATION_ID_ERROR = 0xC7,
	ERROR_CODE_EVENT_PATTERN_CODE_SPEED_NOT_SPECIFIED = 0xC8,
	ERROR_CODE_EVENT_PATTERN_NOT_SPECIFIED = 0xC9,
	ERROR_CODE_EVENT_TIMING_ERROR = 0xCA,
	ERROR_CODE_EVENT_MISSING_TRANSMIT_DURATION = 0xCB,
	ERROR_CODE_EVENT_MISSING_START_TIME = 0xCC,
	ERROR_CODE_EVENT_NOT_CONFIGURED = 0xCD,
    ERROR_CODE_ILLEGAL_COMMAND_RCVD = 0xCE,
    ERROR_CODE_SW_LOGIC_ERROR = 0xCF,
	ERROR_CODE_EVENT_ENDED_IN_PAST = 0xD0,
	ERROR_CODE_ATMEGA_NOT_RESPONDING = 0xD1,
	ERROR_CODE_RF_OSCILLATOR_ERROR = 0xD2,
	ERROR_CODE_DISPLAY_NONRESPONSIVE = 0xE0,
	ERROR_CODE_POWER_LEVEL_NOT_SUPPORTED = 0xF5,
	ERROR_CODE_NO_ANTENNA_PREVENTS_POWER_SETTING = 0xF6,
	ERROR_CODE_NO_ANTENNA_FOR_BAND = 0xF7,
	ERROR_CODE_WD_TIMEOUT = 0xF8,
	ERROR_CODE_SUPPLY_VOLTAGE_ERROR = 0xF9,
	ERROR_CODE_BUCK_REG_OUTOFSPEC = 0xFA,
	ERROR_CODE_CLKGEN_NONRESPONSIVE = 0xFB,
	ERROR_CODE_RTC_NONRESPONSIVE = 0xFC,
	ERROR_CODE_DAC3_NONRESPONSIVE = 0xFD,
	ERROR_CODE_DAC2_NONRESPONSIVE = 0xFE,
	ERROR_CODE_DAC1_NONRESPONSIVE = 0xFF
	} EC;

/*******************************************************/
/* Status Codes                                                                 */
/*******************************************************/
typedef enum {
	STATUS_CODE_IDLE = 0x00,
	STATUS_CODE_REPORT_IDLE = 0x01,
	STATUS_CODE_NO_ANT_ATTACHED = 0xE9,
//	STATUS_CODE_2M_ANT_ATTACHED = 0xEA,
	STATUS_CODE_80M_ANT_ATTACHED = 0xEB,
	STATUS_CODE_RECEIVING_EVENT_DATA = 0xEC,
	STATUS_CODE_RETURNED_FROM_SLEEP = 0xED,
	STATUS_CODE_BEGINNING_XMSN_THIS_CYCLE = 0xEE,
	STATUS_CODE_SENDING_ID = 0xEF,
	STATUS_CODE_NO_EVENT_TO_RUN = 0xFA,
	STATUS_CODE_EVENT_NEVER_ENDS = 0xFB,
	STATUS_CODE_EVENT_FINISHED = 0xFC,
	STATUS_CODE_EVENT_STARTED_NOW_TRANSMITTING = 0xFD,
	STATUS_CODE_EVENT_STARTED_WAITING_FOR_TIME_SLOT = 0xFE,
	STATUS_CODE_WAITING_FOR_EVENT_START = 0xFF
	} SC;

typedef enum {
	DO_NOT_SLEEP,
	SLEEP_UNTIL_START_TIME,
	SLEEP_AFTER_EVENT,
	SLEEP_UNTIL_NEXT_XMSN,
	SLEEP_USER_OVERRIDE,
	SLEEP_FOREVER
	} SleepType;
	

typedef enum {
	DO_NOT_ENUNCIATE,
	LED_AND_RF,
	LED_ONLY
	} Enunciation_t;
	
#define ENUNCIATION_BLINK_WPM 8

/*******************************************************/

#define NO_ADC_SELECTED 255

#ifndef uint16_t_defined
#define uint16_t_defined
typedef unsigned int uint16_t;
#endif

#ifndef uint32_t_defined
#define uint32_t_defined
typedef unsigned long uint32_t;
#endif

#ifndef unit8_t_defined
#define unit8_t_defined
typedef unsigned char uint8_t;
#endif

#ifndef null
#define null 0
#endif

#ifndef PI
#define PI 3.141592653589793
#endif

#ifndef MINUTE
#define MINUTE 60UL
#endif

#ifndef HOUR
#define HOUR 3600UL
#endif

#ifndef DAY
#define DAY 86400UL
#endif

#ifndef YEAR
#define YEAR 31536000UL
#endif

#ifndef UINT16_MAX
#define UINT16_MAX 0xFFFFU
#endif

/*******************************************************/
/*******************************************************
* ADC Scale Factors */
/* Battery voltage should be read when +12V supply is enabled and all transmitters are fully powered off */
#define ADC_REF_VOLTAGE_mV 2048UL
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

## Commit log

2023-11-04 First KiCad Upload
    Version 0.2
    [SignalSnagger.kicad_pcb, SignalSnagger.kicad_sch]
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2023-11-05 Schematic Update
    DF Antenna Corrections
    [SignalSnagger.kicad_sch, audio.kicad_sch, df_antenna.kicad_sch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]
2023-11-05 Ver 0.6
    Schematic updates
    [SignalSnagger.kicad_sch, audio.kicad_sch, processor.kicad_sch]
2023-11-05 Ver 0.6
    Re-annotated and ERC'd
    [SignalSnagger.kicad_sch]
2023-11-05 Ver 0.7
    Schematic update
    [SignalSnagger.kicad_sch, audio.kicad_sch, processor.kicad_sch]
2023-11-05 Ver 0.9
    Schematic corrections and cleanup
    [SignalSnagger.kicad_sch, audio.kicad_sch, processor.kicad_sch]
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2023-11-05 Ver 0.10
    More schematic cleanup
    [SignalSnagger.kicad_sch, audio.kicad_sch, processor.kicad_sch]
2023-11-06 Rev 0.11
    o Added missing DF loop center tap ground
    [SignalSnagger.kicad_sch, audio.kicad_sch, processor.kicad_sch]
2023-11-06 Ver 0.12
    Added antenna diagram sheet.
    [SignalSnagger.kicad_sch, antenna_diagram.kicad_sch, audio.kicad_sch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]
2023-11-09 Ver 0.15
    Schematic changes
    [SignalSnagger.kicad_sch, antenna_diagram.kicad_sch, audio.kicad_sch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]
2023-12-11 Schematic Updates
    Added display and rotary encoder
    Added Jerry's changes based on testing
    [SignalSnagger.kicad_sch, antenna_diagram.kicad_sch, audio.kicad_sch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]
2023-12-19 Schematic Updates
    Rev 0.18
    [SignalSnagger.kicad_sch, antenna_diagram.kicad_sch, audio.kicad_sch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]
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2023-12-20 Schematic Updates
    First cut at prototype design
    [SignalSnagger.kicad_sch, antenna_diagram.kicad_sch, audio.kicad_sch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]
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2023-12-30 Removed Warnings
    Trivial changes to remove DRC warnings
    [SignalSnagger.kicad_sch, processor.kicad_sch]
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2024-02-03 Stereo Support
    Updates to Audio schematic to reflect discussions regarding stereo support.
    [SignalSnagger.kicad_sch, antenna_diagram.kicad_sch, audio.kicad_sch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]
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2024-02-10 V 0.27
    More updates to rotary encoder interface.
    [SignalSnagger.kicad_sch, antenna_diagram.kicad_sch, audio.kicad_sch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]
2024-02-10 Update SignalSnagger.kicad_pcb
    Added KT-70 PCB outline into PCB Editor
    [SignalSnagger.kicad_pcb]
2024-02-16 Rev 0.28
    Adding footprints to schematic: ~10% done
    [SignalSnagger.kicad_pcb, SignalSnagger.kicad_sch, antenna_diagram.kicad_sch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]
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2024-03-07 Minor Cleanup
    No functional changes, only cosmetic changes to the schematic
    [SignalSnagger.kicad_sch, audio.kicad_sch, processor.kicad_sch]
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2024-03-11 Schematic updates
    Fixes to 10uF capacitors - now they are X6S size 0603.
    [SignalSnagger.kicad_sch, audio.kicad_sch, processor.kicad_sch]
2024-03-12 Schematic Updates
    Ver 0.300
    All parts have been assigned DigiKey part numbers where appropriate, and have reasonable (but perhaps not perfect) footprints assigned to them.
    [SignalSnagger.kicad_sch, antenna_diagram.kicad_sch, audio.kicad_sch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]
2024-03-12 Rev 0.301
    PCB Updates - first import from schematic
    Schematic Updates - fixes for various footprints
    [SignalSnagger.kicad_pcb, SignalSnagger.kicad_sch, antenna_diagram.kicad_sch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]
2024-03-15 PCB & Schematic Updates
    Removed parts not targeted for first prototype
    Made other changes discussed in Zoom call
    Updated BOM
    Updated PCB with new parts list
    Noodled with parts placement on PCB
    [SignalSnagger.kicad_pcb, SignalSnagger.kicad_sch, antenna_diagram.kicad_sch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]
2024-03-15 Ver 0.303
    Schematic and PCB updates.
    Added R122.
    [SignalSnagger.kicad_pcb, SignalSnagger.kicad_sch, antenna_diagram.kicad_sch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]
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2024-03-15 Ver 0.304
    Schematic fixes
    PCB updates
    [SignalSnagger.kicad_pcb, SignalSnagger.kicad_sch, antenna_diagram.kicad_sch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]
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2024-03-16 PCB Updates
    Ver 0.306
    Brought in Jerry's layout of RF components.
    [SignalSnagger.kicad_pcb, SignalSnagger.kicad_sch, antenna_diagram.kicad_sch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]
2024-03-16 Ver 0.307
    o All components are now placed onto the board with not traces drawn
    oRe-added the stereo channel. Parts are numbered starting with 901, so they can be easily identified for not populating or future removal
    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
    [SignalSnagger.kicad_pcb, SignalSnagger.kicad_sch, antenna_diagram.kicad_sch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]
2024-03-17 Ver 0.308
    Schematic and PCB tweaks
    Set board thickness to 1.6mm
    [SignalSnagger.kicad_pcb, SignalSnagger.kicad_sch, antenna_diagram.kicad_sch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]
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2024-03-27 Ver 0.311
    All PCB connections have been made
    Design rule check returns no errors or warnings
    Still need to examine footprints, trace widths, pour coverage, etc.
    First Gerbers built
    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
    [SignalSnagger-B_Cu.gbr, SignalSnagger-B_Mask.gbr, SignalSnagger-B_Paste.gbr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]
2024-03-29 Ver 0.312
    BOM updates
    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
    [SignalSnagger.kicad_sch, antenna_diagram.kicad_sch, audio.kicad_sch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]
2024-03-30 Rev 0.313
    Schematic, BOM, and PCB updates to add sense switch power-on feature.
    [SignalSnagger.kicad_sch, antenna_diagram.kicad_sch, audio.kicad_sch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]
2024-03-30 Gerber Updates
    Fixes to Gerber files
    [SignalSnagger-B_Cu.gbr, SignalSnagger-B_Mask.gbr, SignalSnagger-B_Paste.gbr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]
2024-03-31 Ver 0.314
    Corrected footprint for U102
    [SignalSnagger-B_Cu.gbr, SignalSnagger-B_Mask.gbr, SignalSnagger-B_Paste.gbr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]
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2024-04-06 PCB Updates
    Moved programming header
    Added ribbon cable plugs
    [SignalSnagger.kicad_sch]
2024-04-12 PCB Layout
    Most 3D models have been included in the schematic
    PCB layout places all tall parts on the back of the board
    Added knob to BOM
    [KT-70XXT0 ASS'Y.STEP, PCB.FCStd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]
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2024-04-17 Removed spare sense switches
    Updated schematic and PCB to remove spare sense switches.
    [SignalSnagger.kicad_sch, antenna_diagram.kicad_sch, processor.kicad_sch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]
2024-04-23 Gerber Update
    Updated Gerbers to latest PCB version.
    [SignalSnagger-B_Cu.gbr, SignalSnagger-B_Mask.gbr, SignalSnagger-B_Paste.gbr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]
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2024-04-25 Gerber rebuild
    Rebuilt all Gerber files again to ensure they are all up to date, including the zip file.
    [SignalSnagger-B_Cu.gbr, SignalSnagger-B_Mask.gbr, SignalSnagger-B_Paste.gbr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]
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2024-05-04 Schematic PDF File
    Updated date on schematic and printed an updated PDF schematic. No changes made to design.
    [SignalSnagger.kicad_sch, antenna_diagram.kicad_sch, audio.kicad_sch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]
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2024-05-27 Ver 0.09
    o Quadrature for QSD is now working
    o Frequency is now set using the rotary encoder
    o PWM is now set using the rotary encoder
    o Frequency, PWM, and ASSI are all display on the LCD
    o Certain hardware failures are detected and indicated on the LCD
    [defs.h, main.cpp, si5351.cpp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]
2024-06-01 Updated Schematic
    o Updated T101 to accept Coilcraft part
    o Added J208 to support an external I2C module
    o Added D206 to block battery voltage
    o Updated PCB with changes above
    o Corrected silkscreen
    [SignalSnagger-B_Cu.gbr, SignalSnagger-B_Mask.gbr, SignalSnagger-B_Paste.gbr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]
2024-06-03 Schematic and PCB Updates
    o Changed power rating of R320 and R909
    o Changed Q201 to a 1-Amp part
    o Updated Gerbers
    [SignalSnagger-B_Cu.gbr, SignalSnagger-B_Mask.gbr, SignalSnagger-B_Paste.gbr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]
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2024-06-03 BOM Correction
    o Corrected the part associated with U103 (should be a 2.5V reference)
    [SignalSnagger.kicad_sch, audio.kicad_sch]
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2024-06-04 Ver 0.319
    o Shorted PE2 and PE3 together to support both 8-bit and 16-bit TCA-generated PWM
    o Added J209 to support an external module requiring RS232 comms
    [SignalSnagger-B_Cu.gbr, SignalSnagger-B_Mask.gbr, SignalSnagger-B_Paste.gbr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]
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2024-06-07 PWM EMI
    Added changes to schematic and PCB layout to address EMI issues
    [SignalSnagger.kicad_sch]
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2024-07-07 Ver 0.23
    o Added 20 memory channels of frequency storage. Access with long rotary shaft press
    o Implemented a memory mode. Access with three presses on the rotary shaft
    o Changed frequency display to kHz
    o Fixes PWM frequency
    o Added an audio "tick" when rotary knob is turned
    [adc.cpp, defs.h, display.cpp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]
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2024-07-10 Ver 0.25
    o Rotary bug fixes
    o Beginnings of menu system
    [defs.h, eeprommanager.cpp, main.cpp]
2024-07-11 Ver 0.27
    o Menu bug fixes
    o Supports erasing a memory channel
    [defs.h, eeprommanager.cpp, main.cpp]
2024-07-11 Ver 0.28
    Fixes memory bug when no memories are programmed
    Fixes memory bug when only one memory is programmed
    [binio.cpp, defs.h, main.cpp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]
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2024-07-13 Ver 0.31
    o Fixes ADC battery voltage sampling anomaly
    o RF gain now has 10 settings that can be individually adjusted for gain
    [adc.cpp, defs.h, main.cpp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]
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2024-07-17 Ver 0.34
    o Bug fixes
    o Adds the ability to set a battery warning threshold % value
    o Displays a battery warning on start-up if the battery is below the set threshold
    [defs.h, eeprommanager.cpp, main.cpp]
2024-07-20 Ver 0.35
    First version with partial DSP functionality. LEDs illuminate to indicate signal detection: green = signal; red = noise
    [defs.h, main.cpp]
2024-08-22 Ver 0.36
    o EEPROM update - it now stores the last memory used
    o RSSI - Improvements to signal detection
    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
    [defs.h, eeprommanager.cpp, main.cpp]
2024-09-11 Ver 0.37
    o Fixes some power-off bugs
    o Improves headphones removal message
    o Increases audio sample rate to 48 ksps
    [adc.cpp, defs.h, main.cpp]
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2026-10-25 Promote SignalSnagger 0.38.4 to main (#32)
    * Stabilize single-bin signal detection
    * Lower RF gain cue pitch and shorten Morse timing
    * Add separate firmware and KiCad collector workflows
    * Add power-on clock display
    * Add selectable 10 Hz tuning
    * Require SPICE checks for KiCad promotion
    * Integrate receiver input handling and direction indicators (#30)
    Integrate the multi-press and menu timeout handling, restrict receiver-mode toggles to the normal display, preserve the active memory when returning from VFO, and show the active cardioid path on the direction LEDs.
    * Prepare SignalSnagger 0.38.4 release (#31)
2026-11-02 Release SignalSnagger v0.38.5 (#41)
    * Record SignalSnagger 0.38.4 release evidence (#33)
    * Restore sensitivity and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
